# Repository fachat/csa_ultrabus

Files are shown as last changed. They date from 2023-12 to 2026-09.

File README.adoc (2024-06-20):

= csa_ultrabus
A backplane for CS/A, Apple II and RC2014 boards

Note: this can be used stand-alone, but is also a part of a larger set of repositories, with https://github.com/fachat/upet_family[upet_family] as the main repository.

The purpose of this backplane is to cross-enable the use of Apple II expansion cards and RC2014 boards 
on the CS/A65 bus http://www.6502.org/users/andre/csa/bus-1.1.html 

== General Discussion

The board combines three different types of busses:

CS/A65 bus:: 
	A 6502-based bus, with specific select lines and features.
	As, the main CPU uses an MMU, it has 20 address lines (A0-A19)
	to accomodate 1MByte of address space, and using the /MEMSEL
	line to select access to that space. Bank selection needs
	to be taken into account when accessing cards on the other 
	busses. A second select line /IOSEL selects a separate I/O space.
	It is 2k in size, but cards should preferrably be in the first
	256 byte.
	The rev 2 boards now have the long CS/A connectors, as well as 
	the short CS/A connectors. They are also specifically made to be
	used as extension bus to the [Ulti-PET](https://github.com/fachat/cbm_ultipet) machine.

Apple II::
	Apple II expansion slots are also 6502-based. The Apple II uses
	geographic addressing, i.e., each slot has a defined address 
	independent from which card is inserted. This means that address
	selection logic must be included on the board.

RC2014::
	This actually is a Z80-based bus, but boards exist that are
	actually built on 65xx/68xx-based chips - like the 6850-based
	serial interface card. The bus interface is severely different
	with /RD and /WR instead of R/-W and clock.
	Some boards even require timing on the select lines (only
	available on one RC2014 slot here)
	This has to be taken into account.

RC6502::
	This is a variation of the RC2014 bus. Unfortunately it is a 
	very raw mapping of the 6502 bus signals onto the bus.
	Therefore, it does not provide the ability to select specific
	memory areas. As it has 64k address space only, it is 
	only useful if an Apple II CPU is used, or the RC6502 is the
	CPU itself.

== Use Cases

=== CS/A main CPU using A2 and RC2014 boards

The CS/A main CPU uses a 6502, and has an MMU that extends the upper four
bits of the CPU address bus into eight bits, to create a physical 
address space of 1M, that can be selected on the bus.

As the typical system (e.g. PETCPU, or CPU+BIOS) fully occupies the
bank zero space (the lowest 64k on the bus address space),
the memory on the cards on the other busses have to be mapped into some other bank.
This can be done using jumpers.

For A2 boards, the I/O space is set to $02Cxxx, with the special geographic addressing taking place.
So, in the second 128 bytes all the I/O of the cards is located ($C08x-$C0Fx). These 128 byte can be
mapped into memory like in the Apple II, but also onto the /IOSEL space.

Memory access via the /MEMSEL line can be mapped to the /MREQ address space on the RC2014 line.
The /IOSEL line can be mapped to the /IOREQ address space on the RC2014
bus. 

=== CS/A UltraCPU using A2 and RC2014 boards

The UltraCPU works similar to the CS/A main CPU. Internally it uses all of bank zero.
It has one feature, however, that allows it to open up a window to the bus at either
$9xxx or $Cxxx. 

Therefore, the Apple II I/O window can be re-mapped to $009xxx or $00Cxxx on the CS/A bus.

=== Apple II DMA on a CS/A CPU/UltraCPU

Apple II cards can ask for a DMA slot, by pulling the /DMA line down. This separates the CS/A CPU
from the bus - i.e., puts the address, data, and control lines R/-W, /MEMSEL, /IOSEL, SYNC into high
impedance mode on the CPU board. The Apple II card then has to take over these lines.
As /MEMSEL does not exist on the A2 Bus, and the CS/A bus has four more address lines, these
lines are pulled low to auto-create an access to bank zero for any DMA triggered by an Apple II board.

This also enables the /MREQ address space on the RC2014 boards, so memory on these boards
can be used as well. Care has to be taken to not create bus conflicts by overlapping
address spaces.

It should be noted that any memory on a CPU board - UltraCPU specifically - cannot be 
addressed this way. Also, the CS/A PETCPU board lacks this feature. So, this is only
useful for a CPU+MMU+BIOS board system.

=== Apple II using CS/A and RC2014 boards

If there is a CPU board on the A2 bus that wants to take over the whole bus, no CPU board must be
plugged into the CS/A bus. Also, the /DMA feature must be jumpered permanently, to enable
addressing bank zero, and mapping the Apple II slot I/O onto $Cxxx.

This also enables the /MREQ address space on the RC2014 boards, so memory on these boards
can be used as well. Care has to be taken to not create bus conflicts by overlapping
address spaces.

To access CS/A I/O boards, the /IOSEL line needs to be jumpered to /SLOT2IO, so that it is mapped into 
the 256 byte of the Apple II slot 2 ROM space (the Ultrabus offers slots 3, 5, and 7)

To access RC2014 boards, the /IOREQ line must be jumperred to /SLOT6IO, mapping the 256 byte I/O space
into the 256 byte for Apple II slot 6 ROM.

=== RC6502 CPU using Apple II and CS/A boards

There is only one RC6502 slot available, by jumpering one of the RC2014 slots into an RC6502.
As the RC6502 is basically a 6502 bus, A16-A19 and /MEMSEL have to be jumpered to low similar
to the Apple CPU case. Also, the I/O slots are then available using the same mapping as
when the Apple II CPU is a bus master.

=== RC2014 CPU

Using an RC2014 CPU is NOT possible on this board.

== Build

To get the board built, KiCad schematics, gerber files, and a BOM with Mouser part numbers are provided in the repository.

== Revision History

- [R1.0A](https://github.com/fachat/csa_ultrabus/tree/r1.0a): the original Euro-PCB board. Built with Eagle

== Gallery

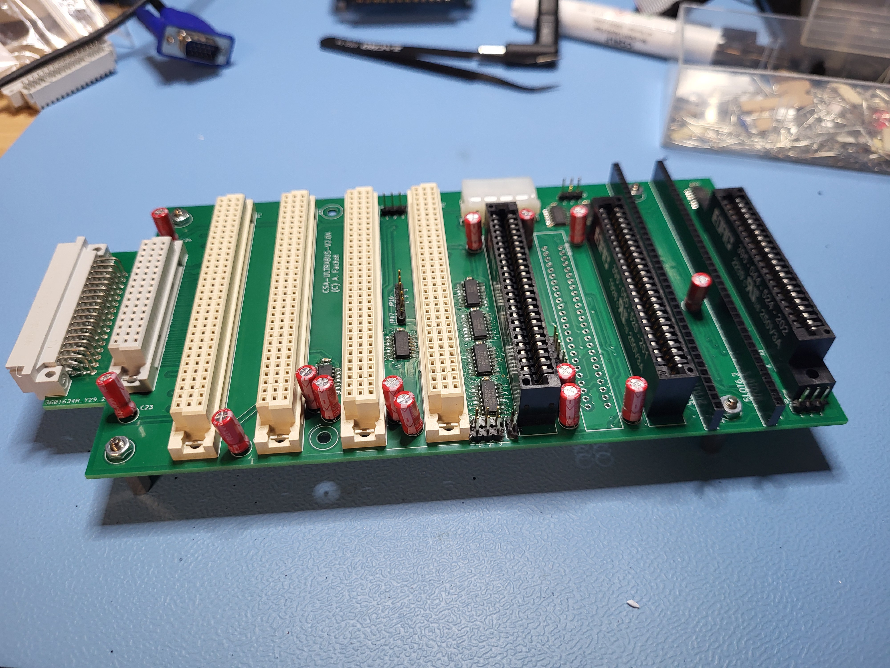
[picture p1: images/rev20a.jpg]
Revision 2.0A
 

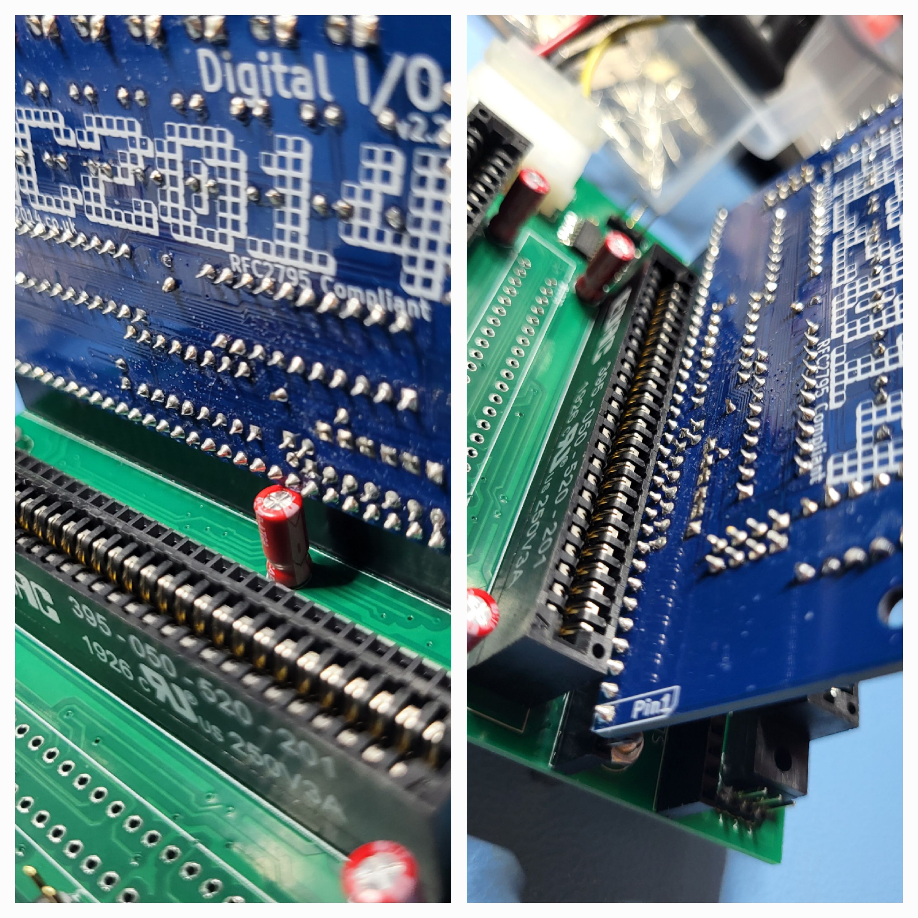
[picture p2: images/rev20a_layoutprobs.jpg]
Layout problems with revision 2.0A - fixed in 2.0B
 

=== Rev 1.0

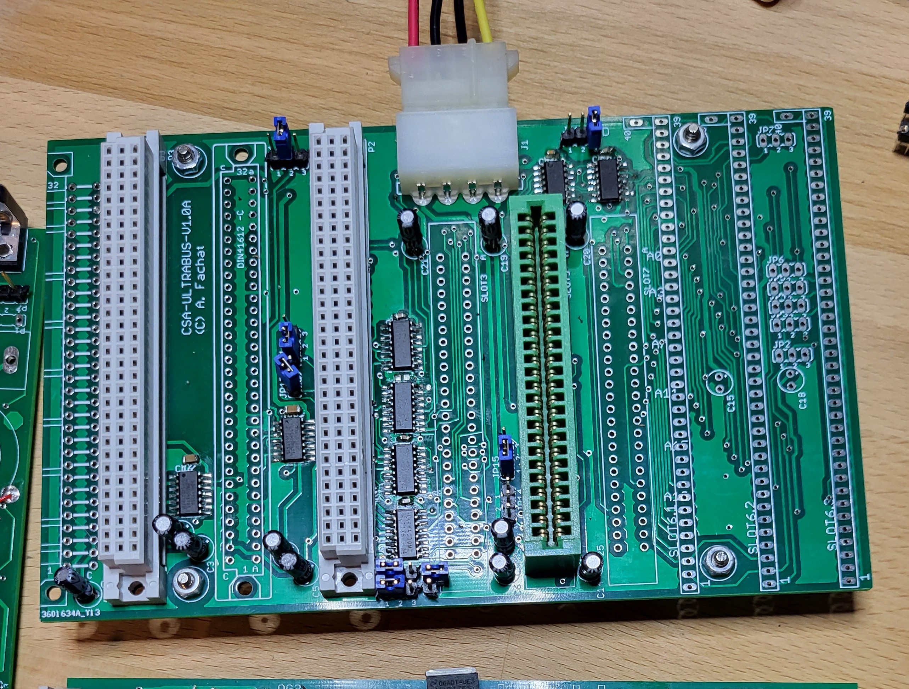
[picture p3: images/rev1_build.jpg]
Partially populated pcb during build
 

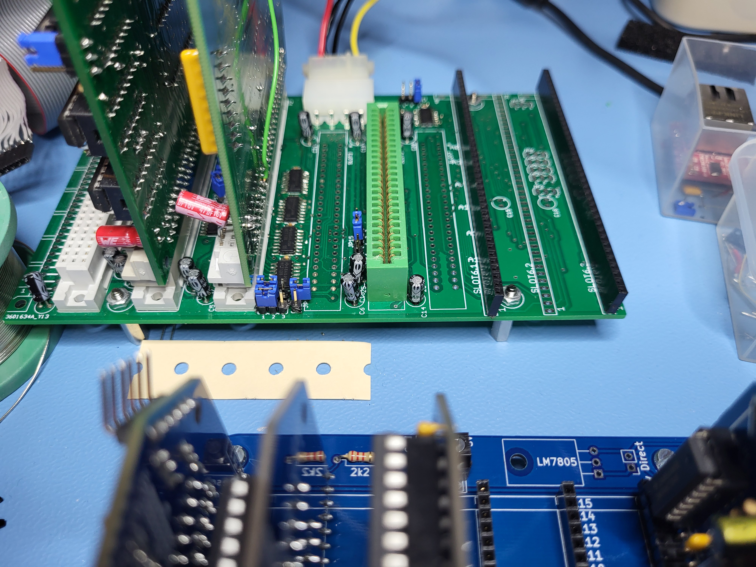
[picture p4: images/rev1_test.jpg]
PCB during test


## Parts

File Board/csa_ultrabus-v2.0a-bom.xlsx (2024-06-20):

Source: | /home/fachat/8bit/8bitgit/Eagle/work/CSA_ULTRABUS_V2.0A/csa_ultrabus_v2.kicad_sch
Date: | Fri Feb 16 13:55:04 2024
Tool: | Eeschema 7.0.10
Generator: | /app/share/kicad/plugins/bom_csv_grouped_by_value_with_fp.py
Component Count: | 62
Ref | Qnty | orig | Value | Cmp name | Footprint | Description | Vendor | DNP | Alt
C1, C3, C4, C5, C6, C13, C14, C15, C17, C18, C19, C20, C21, C23, C24 | 15 |  | 47u | CPOL-EUE2.5-5 | csa_ultrabus_v2:E2,5-5 | POLARIZED CAPACITOR, European symbol | 710-860010372004 | 860010372004
C2, C7, C8, C9, C10, C11, C12, C16, C22 | 9 |  | 100n | C-EUC0603 | csa_ultrabus_v2:C0603 | CAPACITOR, European symbol | 710-885012206020 | 885012206020
IC1 | 1 |  | 7404D | 7404D | csa_ultrabus_v2:SO14 |  | 771-74HCT04D-Q100118 | 74HCT04D-Q100,118
IC2, IC3, IC4, IC5, IC9 | 5 |  | 74138D | 74138D | csa_ultrabus_v2:SO16 |  | 595-SN74HCT138DR | SN74HCT138DR | 771-74HCT138D-T
IC6 | 1 |  | 7400D | 7400D | csa_ultrabus_v2:SO14 |  | 771-74HCT00D-Q100118 | 74HCT00D-Q100,118
IC7, IC8 | 2 |  | 74125D | 74125D | csa_ultrabus_v2:SO14 |  | 771-74HCT125D-Q100J | 74HCT125D-Q100J
J1 | 1 |  | FLOP-4W827001 | FLOP-4W827001 | csa_ultrabus_v2:827001 | MATE N-LOCK Floppy / HDD conector | 571-6417371 | 641737-1 | https://www.reichelt.de/stromversorgungsstecker-f-5-1-4-zoll-print-gew--psw-5-p14915.html?trstct=pol_3&nbc=1
JP1, JP2, JP9, JP10, JP11, JP14, JP15, JP16 |  | 8 | JP2E | JP2E | csa_ultrabus_v2:JP2
JP8, JP17 |  | 2 | JP1E | JP1E | csa_ultrabus_v2:JP1
 | 1 |  |  |  |  | pin strip straight 20 pin | 649-1012937892001BLF | 10129378-920001BLF
P1, P2, P3, P4 | 4 |  | CSABUSSOCK180 | CSABUSSOCK180 | csa_ultrabus_v2:CSABUSSOCK180 |  | 649-8609464814T5F1LF | 86094648114T55F1LF
SLOT3, SLOT5, SLOT7 | 3 |  | A2SLOT | A2SLOT | csa_ultrabus_v2:FE100-25 |  | 587-395-050 | 395-050-520-202 | 587-395-050-520-201 | 395-050-520-201
SLOT6.1, SLOT6.2 | 2 |  | RC2014/6502 | RC2014/6502 | csa_ultrabus_v2:SIL40 |  | 200-SSW14006TS | SSW-140-06-T-S | 872-920-0215-01 | 920-0215-01
U$1 | 1 |  | CSASHORTBUSFS | CSASHORTBUSFS | csa_ultrabus_v2:FABC48S2 |  | 649-93488314H55V1LF | 86093488314H55V1LF
U$2 | 1 |  | CSASHORTBUSMA | CSASHORTBUSMA | csa_ultrabus_v2:MABC48B2 |  | 649-8693487313765ELF | 86093487313765ELF
X1 | 1 |  | PORT_EXPANSION_64_CONN | PORT_EXPANSION_64_CONN | csa_ultrabus_v2:FE100-22-2 |  | 587-395-044 | 395-044-520-202

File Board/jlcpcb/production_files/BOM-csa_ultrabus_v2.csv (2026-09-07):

Comment | Designator | Footprint | LCSC | Quantity
0 | R25,R26,R27,R28 | R_0603_1608Metric_Pad0.98x0.95mm_HandSolder | C21189 | 4
0.01uF low ESR | C41 | C_0603_1608Metric_Pad1.08x0.95mm_HandSolder | C57112 | 1
1.1k | R10 | R_0603_1608Metric_Pad0.98x0.95mm_HandSolder | C22764 | 1
100k | R8 | R_0603_1608Metric_Pad0.98x0.95mm_HandSolder | C25803 | 1
100n | C25,C31,C32,C37,C40,C43,C46 | C_0603_1608Metric_Pad1.08x0.95mm_HandSolder | C14663 | 7
10k | R1,R14,R18,R22,R30,R36,R39,R41,R43,R9 | R_0603_1608Metric_Pad0.98x0.95mm_HandSolder | C25804 | 10
10u | C27,C28,C29,C35,C36,C38 | C_1206_3216Metric_Pad1.33x1.80mm_HandSolder | C33546014 | 6
15uH | L2 | L_APV_APH0630 | C5189959 | 1
1N4148 | D11,D12 | D_SOD-323_HandSoldering | C2128 | 2
1k, >=0.3W | R29 | R_0603_1608Metric_Pad0.98x0.95mm_HandSolder | C5886053 | 1
1u | C26 | C_1206_3216Metric_Pad1.33x1.80mm_HandSolder | C1848 | 1
2.2k | R37,R42 | R_0603_1608Metric_Pad0.98x0.95mm_HandSolder | C4190 | 2
220u | C42 | CP_Elec_10x10 | C125977 | 1
22u | C30,C33,C34,C39,C45,C47 | C_1206_3216Metric_Pad1.33x1.80mm_HandSolder | C12891 | 6
2k2 | R13,R33,R34,R45,R46,R47,R48,R6 | R_0603_1608Metric_Pad0.98x0.95mm_HandSolder | C4190 | 8
36k | R11,R35 | R_0603_1608Metric_Pad0.98x0.95mm_HandSolder | C23147 | 2
3k3 | R4 | R_0603_1608Metric_Pad0.98x0.95mm_HandSolder | C22978 | 1
4.7uH | L1 | L_APV_ANR4030 | C57269 | 1
420 | R12,R5 | R_0603_1608Metric_Pad0.98x0.95mm_HandSolder | C23057 | 2
47k | R17 | R_0603_1608Metric_Pad0.98x0.95mm_HandSolder | C25819 | 1
47u | C1,C13,C14,C15,C17,C18,C19,C20,C21,C23,C24,C3,C4,C5,C6 | E2,5-5 | C713185 | 15
5.1k | R7 | R_0603_1608Metric_Pad0.98x0.95mm_HandSolder | C23186 | 1
560 | R38,R44 | R_0603_1608Metric_Pad0.98x0.95mm_HandSolder | C23204 | 2
680 | R16,R20,R24 | R_0603_1608Metric_Pad0.98x0.95mm_HandSolder | C23228 | 3
7400D | IC6 | SO14 | C282337 | 1
7404D | IC1 | SO14 | C6766 | 1
74125D | IC7,IC8 | SO14 | C5962 | 2
74138D | IC2,IC3,IC4,IC5,IC9 | SO16 | C352958 | 5
8.2k | R21 | R_0603_1608Metric_Pad0.98x0.95mm_HandSolder | C25981 | 1
8.6k | R40 | R_0603_1608Metric_Pad0.98x0.95mm_HandSolder | C2924154 | 1
A2SLOT | SLOT3,SLOT5,SLOT7 | FE100-25 | C5173308 | 3
AP63205WU | U1 | TSOT-23-6 | C2071056 | 1
B340A | D4 | D_SMA_Handsoldering | C3018525 | 1
BC847 | Q7,Q8 | SOT-23 | C7420337 | 2
BC857 | Q1,Q2,Q3 | SOT-23 | C20069137 | 3
C-EUC0603 | C10,C11,C12,C16,C2,C22,C7,C8,C9 | C0603 | C14663 | 9
CH224K | U9 | SSOP-10-1EP_3.9x4.9mm_P1mm_EP2.1x3.3mm | C970725 | 1
CSABUSSOCK180 | P1,P2,P3,P4 | CSABUSSOCK180 | C53202145 | 4
CSASHORTBUSFS | U$1 | FABC48S2 | C5377847 | 1
CSASHORTBUSMA | U$2 | MABC48B2 | C5173369 | 1
JP1E | JP17,JP18,JP19,JP8 | JP1 | C7494857 | 4
JP2E | JP1,JP10,JP11,JP14,JP15,JP16,JP2,JP9 | JP2 | C6332196 | 8
L7812 | U2 | TO-252-2 | C26184 | 1
L7905 | U5 | TO-252-3_TabPin2 | C962758 | 1
LDI1117 | UX3 | SOT-223 | C6186 | 1
LED | D1,D2,D3,D6,D7 | D_0603_1608Metric_Pad1.05x0.95mm_HandSolder | C12065 | 5
LED | D10,D13,D14,D8,D9 | D_0603_1608Metric_Pad1.05x0.95mm_HandSolder | C7496820 | 5
PORT_EXPANSION_64_CONN | X1 | FE100-22-2 | C21261712 | 1
RC2014/6502 | SLOT6.1,SLOT6.2 | SIL40 | C18078141 | 2
TL431 | U11,U12 | SOT-23 | C181103 | 2
TL431DBZ | U6,U7,U8 | SOT-23 | C181103 | 3
TPS5430DDA | U4 | TI_SO-PowerPAD-8_ThermalVias | C9864 | 1
USB_C_Receptacle_USB2.0_16P | J3 | USB_C_Receptacle_GCT_USB4105-xx-A_16P_TopMnt_Horizontal | C2765186 | 1

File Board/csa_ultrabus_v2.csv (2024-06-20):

Id | Designator | Footprint | Quantity | Designation | Supplier and ref
1 | IC5,IC9,IC3,IC4,IC2 | SO16 | 5 | 74138D
2 | C4,C14,C23,C18,C17,C24,C5,C15,C13,C21,C3,C6,C1,C20,C19 | E2,5-5 | 15 | 47u
3 | JP8,JP17 | JP1 | 2 | JP1E
4 | P2,P4,P3,P1 | CSABUSSOCK180 | 4 | CSABUSSOCK180
5 | C11,C8,C9,C16,C12,C2,C10,C22,C7 | C0603 | 9 | C-EUC0603
6 | JP11,JP15,JP16,JP1,JP14,JP9,JP2,JP10 | JP2 | 8 | JP2E
7 | H2,H5,H6,H1,H4,H3 | 3,2 | 6 | MOUNT-HOLE3.2
8 | SLOT5,SLOT3,SLOT7 | FE100-25 | 3 | A2SLOT
9 | SLOT6.1,SLOT6.2 | SIL40 | 2 | RC2014/6502
10 | U$1 | FABC48S2 | 1 | CSASHORTBUSFS
11 | IC8,IC7 | SO14 | 2 | 74125D
12 | U$2 | MABC48B2 | 1 | CSASHORTBUSMA
13 | IC6 | SO14 | 1 | 7400D
14 | IC1 | SO14 | 1 | 7404D
15 | X1 | FE100-22-2 | 1 | PORT_EXPANSION_64_CONN
16 | R1 | R_Axial_DIN0204_L3.6mm_D1.6mm_P2.54mm_Vertical | 1 | 10k
17 | J1 | 827001 | 1 | FLOP-4W827001

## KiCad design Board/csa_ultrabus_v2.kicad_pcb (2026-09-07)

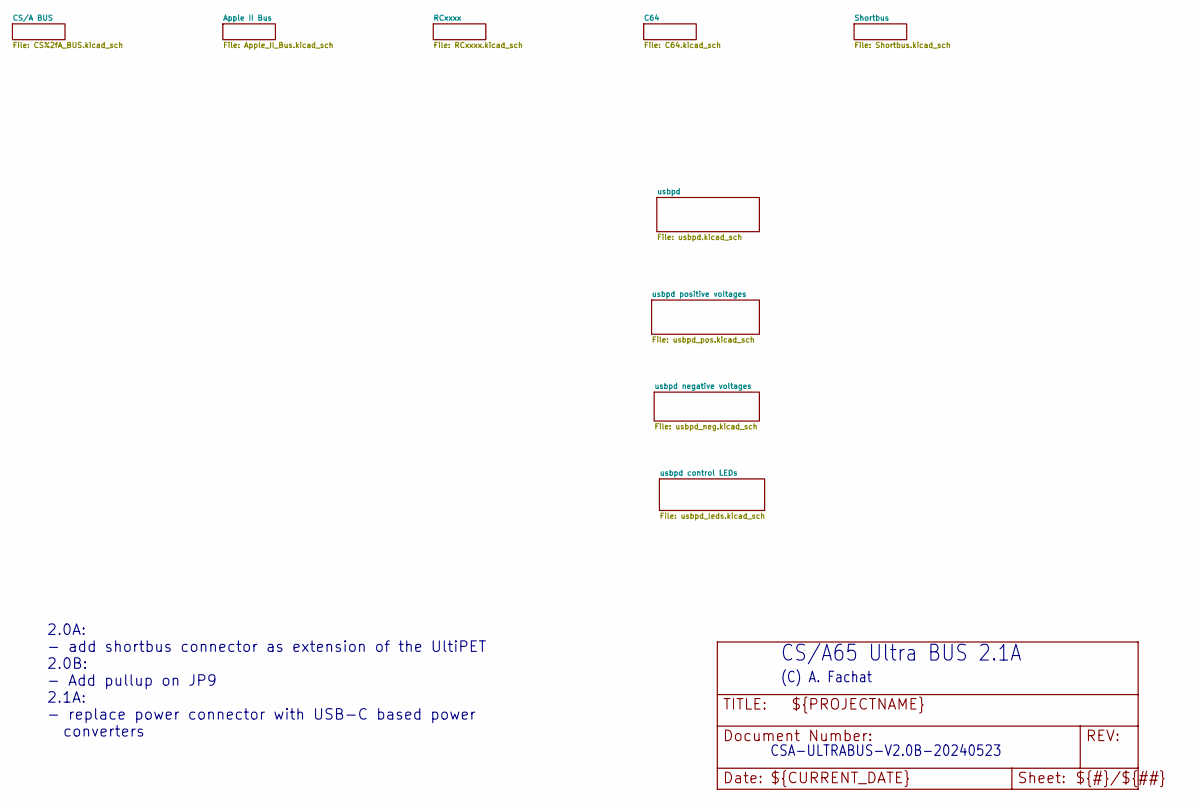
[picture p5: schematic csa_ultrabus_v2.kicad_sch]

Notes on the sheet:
2.0A: - add shortbus connector as extension of the UltiPET 2.0B: - Add pullup on JP9 2.1A: - replace power connector with USB-C based power converters
(C) A. Fachat
CS/A65 Ultra BUS 2.1A
CSA-ULTRABUS-V2.0B-20240523

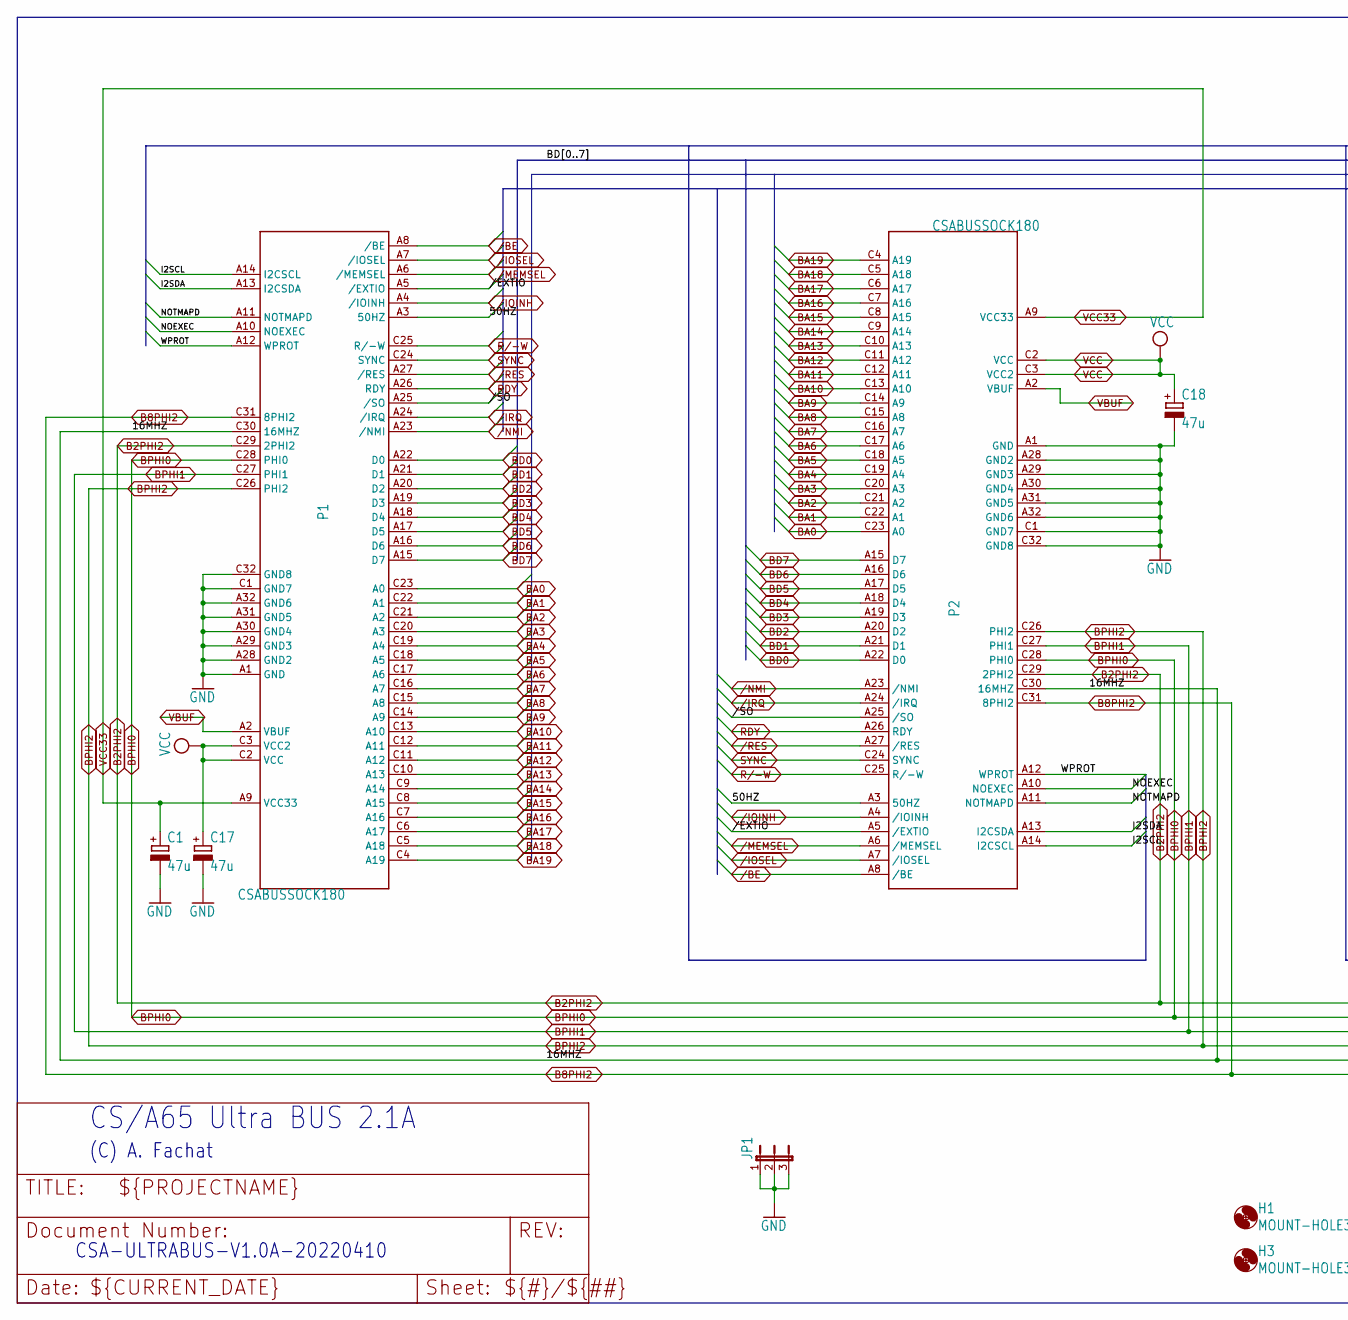
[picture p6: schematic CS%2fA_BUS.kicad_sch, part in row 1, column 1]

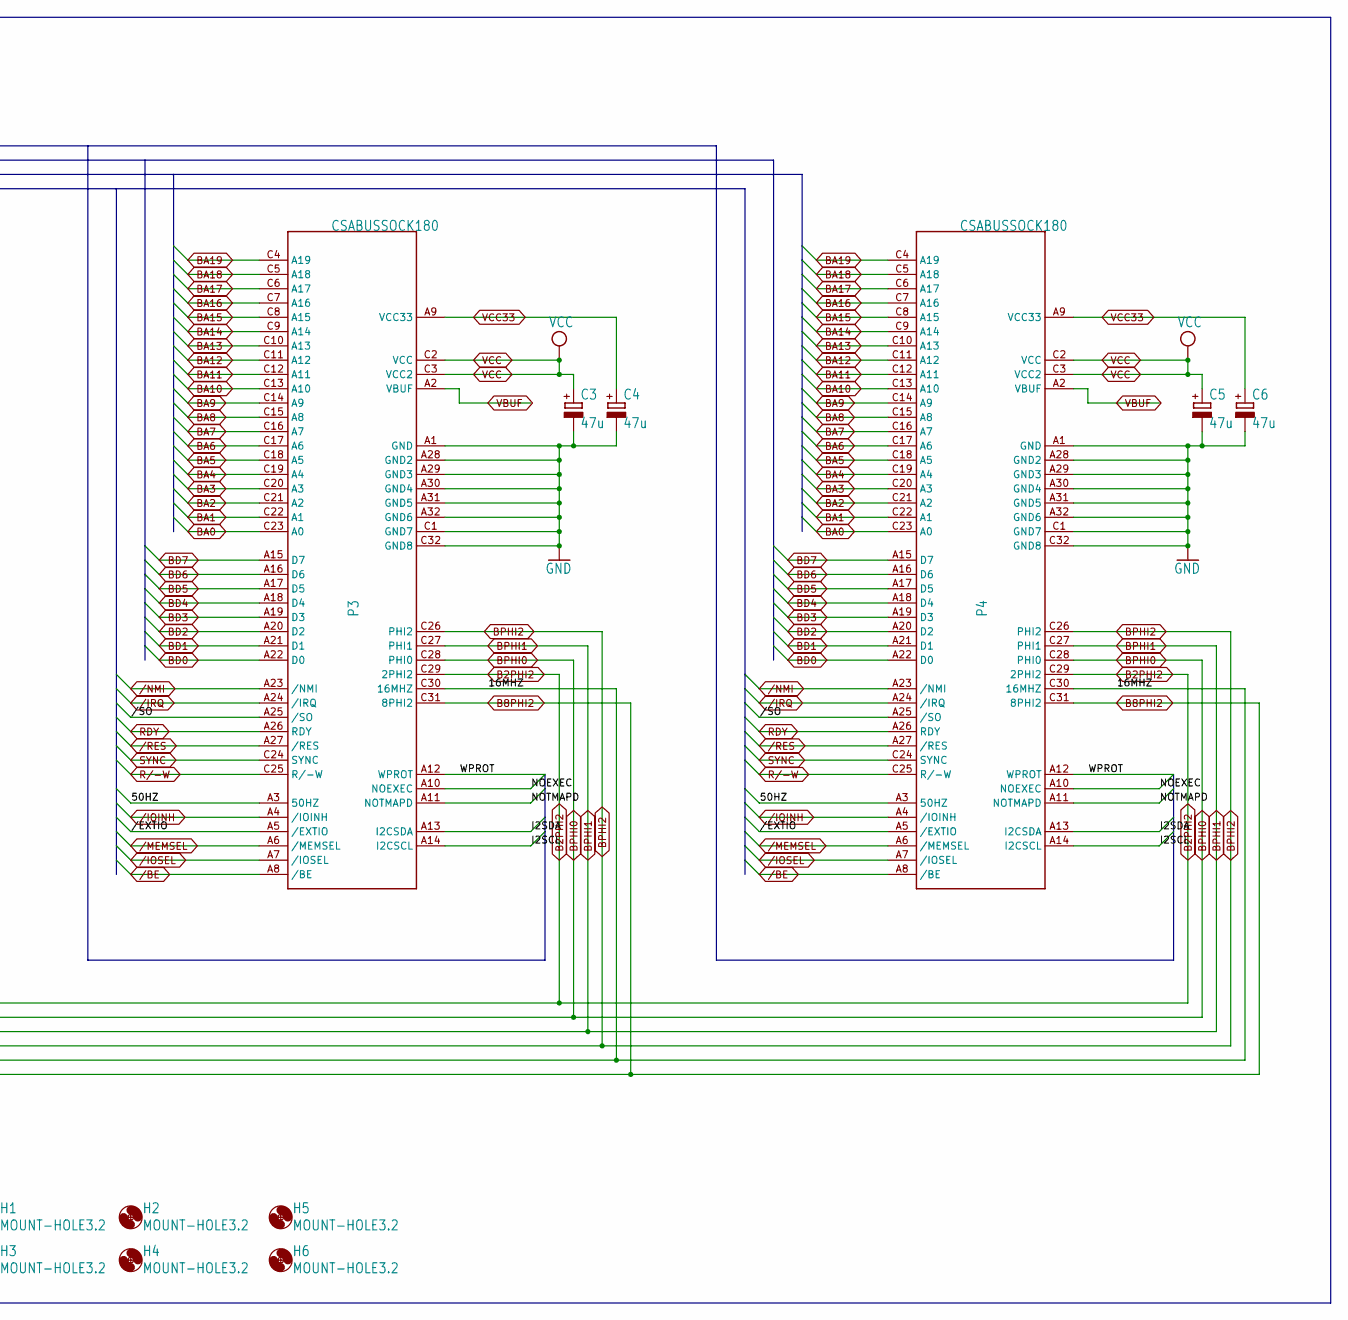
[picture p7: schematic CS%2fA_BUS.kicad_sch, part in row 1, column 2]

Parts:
C1, C3, C4, C5, C6, C17, C18: 47u; E2,5-5; LCSC C713185
H1, H2, H3, H4, H5, H6: MOUNT-HOLE3.2; 3,2
JP1: JP2E; JP2; LCSC C6332196
P1, P2, P3, P4: CSABUSSOCK180; LCSC C53202145

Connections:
5V: C3.+, C5.+, C17.+, C18.+, P1.C2 (VCC), P1.C3 (VCC2), P2.C2 (VCC), P2.C3 (VCC2), P3.C2 (VCC), P3.C3 (VCC2), P4.C2 (VCC), P4.C3 (VCC2); also elsewhere on the board
/CS/A BUS/16MHZ: P1.C30 (16MHZ), P2.C30 (16MHZ), P3.C30 (16MHZ), P4.C30 (16MHZ)
/CS/A BUS/50HZ: P1.A3 (50HZ), P2.A3 (50HZ), P3.A3 (50HZ), P4.A3 (50HZ)
/CS/A BUS/I2SCL: P1.A14 (I2CSCL), P2.A14 (I2CSCL), P3.A14 (I2CSCL), P4.A14 (I2CSCL)
/CS/A BUS/I2SDA: P1.A13 (I2CSDA), P2.A13 (I2CSDA), P3.A13 (I2CSDA), P4.A13 (I2CSDA)
/CS/A BUS/NOEXEC: P1.A10 (NOEXEC), P2.A10 (NOEXEC), P3.A10 (NOEXEC), P4.A10 (NOEXEC)
/CS/A BUS/NOTMAPD: P1.A11 (NOTMAPD), P2.A11 (NOTMAPD), P3.A11 (NOTMAPD), P4.A11 (NOTMAPD)
/CS/A BUS/WPROT: P1.A12 (WPROT), P2.A12 (WPROT), P3.A12 (WPROT), P4.A12 (WPROT)
/CS/A BUS//EXTIO: P1.A5 (/EXTIO), P2.A5 (/EXTIO), P3.A5 (/EXTIO), P4.A5 (/EXTIO)
/CS/A BUS//SO: P1.A25 (/SO), P2.A25 (/SO), P3.A25 (/SO), P4.A25 (/SO)
B2PHI2: P1.C29 (2PHI2), P2.C29 (2PHI2), P3.C29 (2PHI2), P4.C29 (2PHI2); also elsewhere on the board
B8PHI2: P1.C31 (8PHI2), P2.C31 (8PHI2), P3.C31 (8PHI2), P4.C31 (8PHI2); also elsewhere on the board
BA0: P1.C23 (A0), P2.C23 (A0), P3.C23 (A0), P4.C23 (A0); also elsewhere on the board
BA1: P1.C22 (A1), P2.C22 (A1), P3.C22 (A1), P4.C22 (A1); also elsewhere on the board
BA2: P1.C21 (A2), P2.C21 (A2), P3.C21 (A2), P4.C21 (A2); also elsewhere on the board
BA3: P1.C20 (A3), P2.C20 (A3), P3.C20 (A3), P4.C20 (A3); also elsewhere on the board
BA4: P1.C19 (A4), P2.C19 (A4), P3.C19 (A4), P4.C19 (A4); also elsewhere on the board
BA5: P1.C18 (A5), P2.C18 (A5), P3.C18 (A5), P4.C18 (A5); also elsewhere on the board
BA6: P1.C17 (A6), P2.C17 (A6), P3.C17 (A6), P4.C17 (A6); also elsewhere on the board
BA7: P1.C16 (A7), P2.C16 (A7), P3.C16 (A7), P4.C16 (A7); also elsewhere on the board
BA8: P1.C15 (A8), P2.C15 (A8), P3.C15 (A8), P4.C15 (A8); also elsewhere on the board
BA9: P1.C14 (A9), P2.C14 (A9), P3.C14 (A9), P4.C14 (A9); also elsewhere on the board
BA10: P1.C13 (A10), P2.C13 (A10), P3.C13 (A10), P4.C13 (A10); also elsewhere on the board
BA11: P1.C12 (A11), P2.C12 (A11), P3.C12 (A11), P4.C12 (A11); also elsewhere on the board
BA12: P1.C11 (A12), P2.C11 (A12), P3.C11 (A12), P4.C11 (A12); also elsewhere on the board
BA13: P1.C10 (A13), P2.C10 (A13), P3.C10 (A13), P4.C10 (A13); also elsewhere on the board
BA14: P1.C9 (A14), P2.C9 (A14), P3.C9 (A14), P4.C9 (A14); also elsewhere on the board
BA15: P1.C8 (A15), P2.C8 (A15), P3.C8 (A15), P4.C8 (A15); also elsewhere on the board
BA16: P1.C7 (A16), P2.C7 (A16), P3.C7 (A16), P4.C7 (A16); also elsewhere on the board
BA17: P1.C6 (A17), P2.C6 (A17), P3.C6 (A17), P4.C6 (A17); also elsewhere on the board
BA18: P1.C5 (A18), P2.C5 (A18), P3.C5 (A18), P4.C5 (A18); also elsewhere on the board
BA19: P1.C4 (A19), P2.C4 (A19), P3.C4 (A19), P4.C4 (A19); also elsewhere on the board
BD0: P1.A22 (D0), P2.A22 (D0), P3.A22 (D0), P4.A22 (D0); also elsewhere on the board
BD1: P1.A21 (D1), P2.A21 (D1), P3.A21 (D1), P4.A21 (D1); also elsewhere on the board
BD2: P1.A20 (D2), P2.A20 (D2), P3.A20 (D2), P4.A20 (D2); also elsewhere on the board
BD3: P1.A19 (D3), P2.A19 (D3), P3.A19 (D3), P4.A19 (D3); also elsewhere on the board
BD4: P1.A18 (D4), P2.A18 (D4), P3.A18 (D4), P4.A18 (D4); also elsewhere on the board
BD5: P1.A17 (D5), P2.A17 (D5), P3.A17 (D5), P4.A17 (D5); also elsewhere on the board
BD6: P1.A16 (D6), P2.A16 (D6), P3.A16 (D6), P4.A16 (D6); also elsewhere on the board
BD7: P1.A15 (D7), P2.A15 (D7), P3.A15 (D7), P4.A15 (D7); also elsewhere on the board
BPHI0: P1.C28 (PHI0), P2.C28 (PHI0), P3.C28 (PHI0), P4.C28 (PHI0); also elsewhere on the board
BPHI1: P1.C27 (PHI1), P2.C27 (PHI1), P3.C27 (PHI1), P4.C27 (PHI1); also elsewhere on the board
BPHI2: P1.C26 (PHI2), P2.C26 (PHI2), P3.C26 (PHI2), P4.C26 (PHI2); also elsewhere on the board
GND: C1.-, C3.-, C4.-, C5.-, C6.-, C17.-, C18.-, JP1.1, JP1.2, JP1.3, P1.A1 (GND), P1.A28 (GND2), P1.A29 (GND3), P1.A30 (GND4), P1.A31 (GND5), P1.A32 (GND6), P1.C1 (GND7), P1.C32 (GND8), P2.A1 (GND), P2.A28 (GND2), P2.A29 (GND3), P2.A30 (GND4), P2.A31 (GND5), P2.A32 (GND6), P2.C1 (GND7), P2.C32 (GND8), P3.A1 (GND), P3.A28 (GND2), P3.A29 (GND3), P3.A30 (GND4), P3.A31 (GND5), P3.A32 (GND6), P3.C1 (GND7), P3.C32 (GND8), P4.A1 (GND), P4.A28 (GND2), P4.A29 (GND3), P4.A30 (GND4), P4.A31 (GND5), P4.A32 (GND6), P4.C1 (GND7), P4.C32 (GND8); also elsewhere on the board
RDY: P1.A26 (RDY), P2.A26 (RDY), P3.A26 (RDY), P4.A26 (RDY); also elsewhere on the board
R/-W: P1.C25 (R/-W), P2.C25 (R/-W), P3.C25 (R/-W), P4.C25 (R/-W); also elsewhere on the board
SYNC: P1.C24 (SYNC), P2.C24 (SYNC), P3.C24 (SYNC), P4.C24 (SYNC); also elsewhere on the board
V33: C1.+, C4.+, C6.+, P1.A9 (VCC33), P2.A9 (VCC33), P3.A9 (VCC33), P4.A9 (VCC33); also elsewhere on the board
VBUF: P1.A2 (VBUF), P2.A2 (VBUF), P3.A2 (VBUF), P4.A2 (VBUF); also elsewhere on the board
/BE: P1.A8 (/BE), P2.A8 (/BE), P3.A8 (/BE), P4.A8 (/BE); also elsewhere on the board
/IOINH: P1.A4 (/IOINH), P2.A4 (/IOINH), P3.A4 (/IOINH), P4.A4 (/IOINH); also elsewhere on the board
/IOSEL: P1.A7 (/IOSEL), P2.A7 (/IOSEL), P3.A7 (/IOSEL), P4.A7 (/IOSEL); also elsewhere on the board
/IRQ: P1.A24 (/IRQ), P2.A24 (/IRQ), P3.A24 (/IRQ), P4.A24 (/IRQ); also elsewhere on the board
/MEMSEL: P1.A6 (/MEMSEL), P2.A6 (/MEMSEL), P3.A6 (/MEMSEL), P4.A6 (/MEMSEL); also elsewhere on the board
/NMI: P1.A23 (/NMI), P2.A23 (/NMI), P3.A23 (/NMI), P4.A23 (/NMI); also elsewhere on the board
/RES: P1.A27 (/RES), P2.A27 (/RES), P3.A27 (/RES), P4.A27 (/RES); also elsewhere on the board

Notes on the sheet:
CSA-ULTRABUS-V1.0A-20220410
CS/A65 Ultra BUS 2.1A
(C) A. Fachat

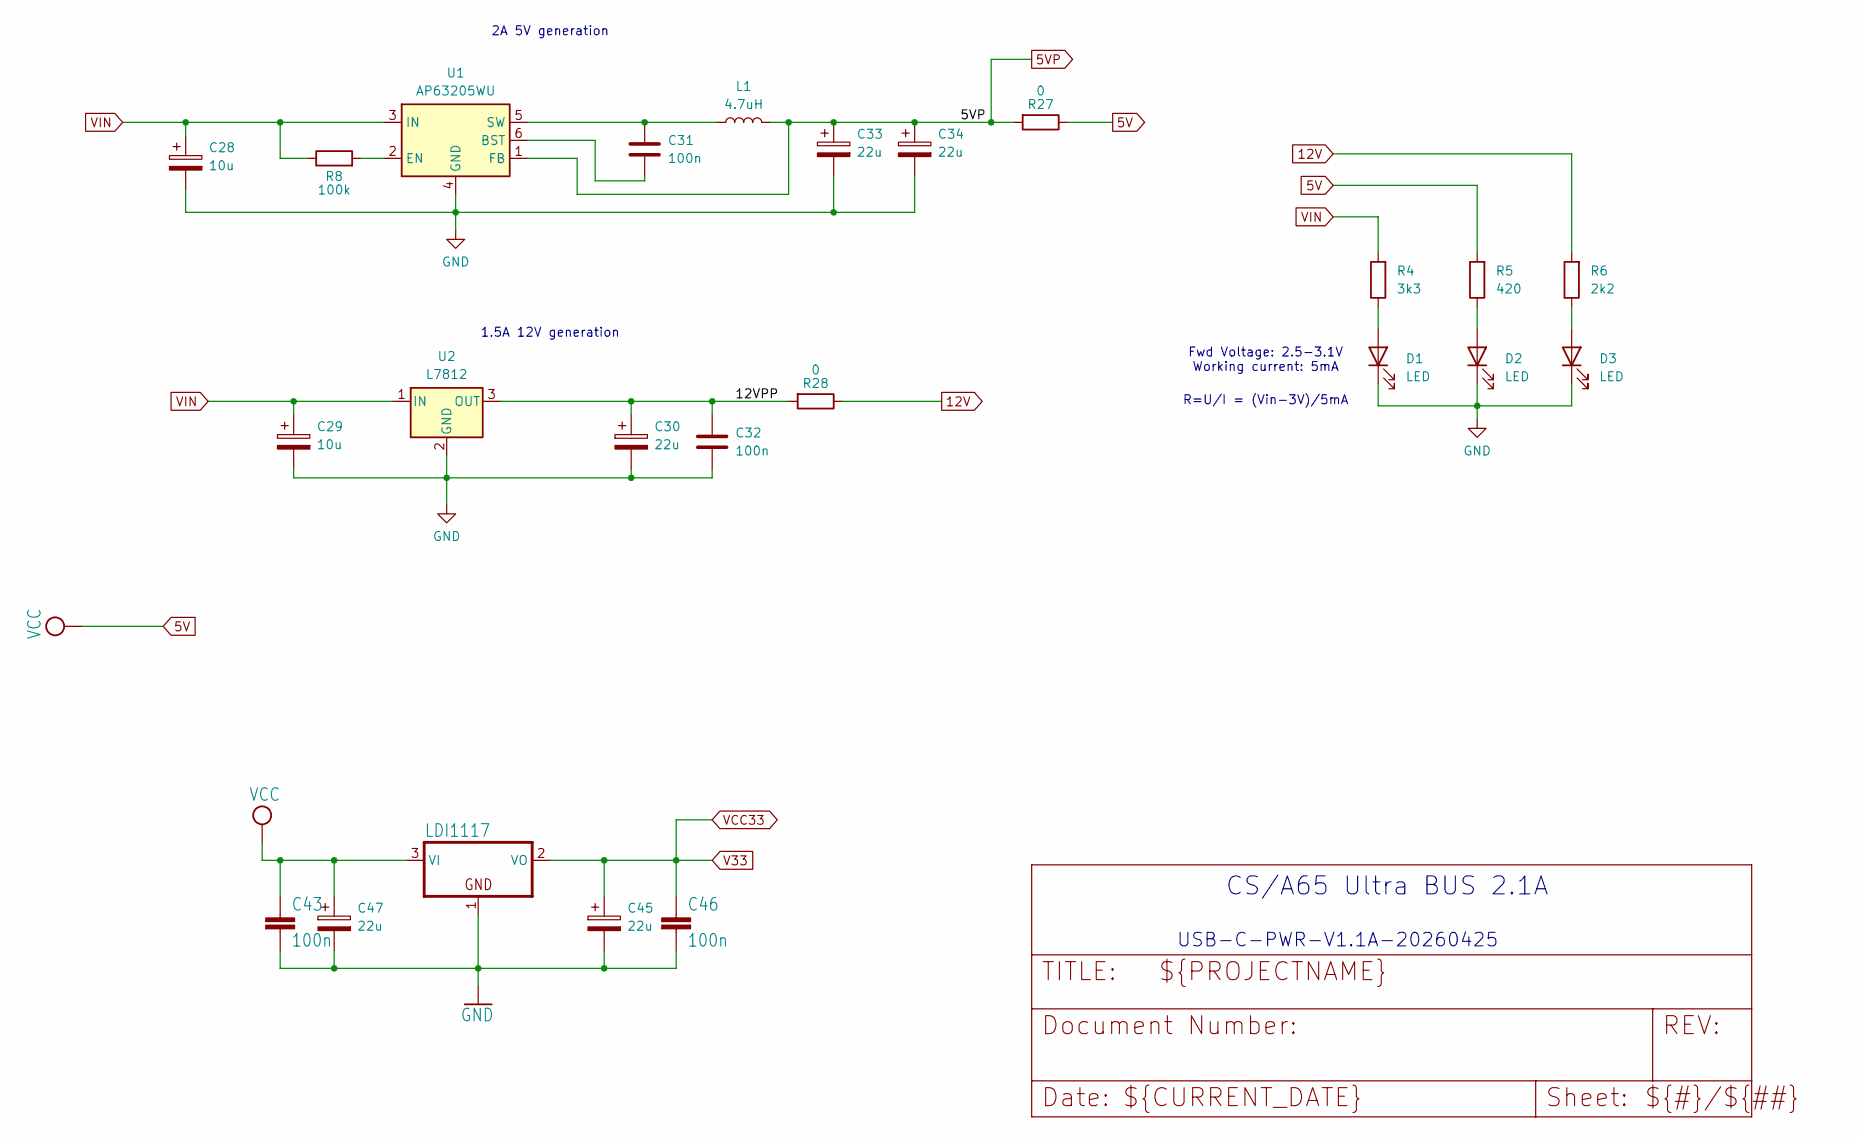
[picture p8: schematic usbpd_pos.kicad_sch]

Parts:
C28, C29: 10u; C_1206_3216Metric_Pad1.33x1.80mm_HandSolder; LCSC C33546014
C30, C33, C34, C45, C47: 22u; C_1206_3216Metric_Pad1.33x1.80mm_HandSolder; LCSC C12891
C31, C32, C43, C46: 100n; C_0603_1608Metric_Pad1.08x0.95mm_HandSolder; LCSC C14663
D1, D2, D3: LED; D_0603_1608Metric_Pad1.05x0.95mm_HandSolder; LCSC C12065
L1: 4.7uH; L_APV_ANR4030; LCSC C57269
R4: 3k3; R_0603_1608Metric_Pad0.98x0.95mm_HandSolder; LCSC C22978
R5: 420; R_0603_1608Metric_Pad0.98x0.95mm_HandSolder; LCSC C23057
R6: 2k2; R_0603_1608Metric_Pad0.98x0.95mm_HandSolder; LCSC C4190
R8: 100k; R_0603_1608Metric_Pad0.98x0.95mm_HandSolder; LCSC C25803
R27, R28: 0; R_0603_1608Metric_Pad0.98x0.95mm_HandSolder; LCSC C21189
U1: AP63205WU; TSOT-23-6; LCSC C2071056
U2: L7812; TO-252-2; LCSC C26184
UX3: LDI1117; SOT-223; LCSC C6186

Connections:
5V: C43.1, C47.1, R5.2, R27.1, UX3.3 (VI); also elsewhere on the board
5VP: C33.1, C34.1, L1.2, R27.2, U1.1 (FB); also elsewhere on the board
12V: R6.2, R28.1; also elsewhere on the board
/usbpd positive voltages/12VPP: C30.1, C32.2, R28.2, U2.3 (OUT)
GND: C28.2, C29.2, C30.2, C32.1, C33.2, C34.2, C43.2, C45.2, C46.2, C47.2, D1.1 (K), D2.1 (K), D3.1 (K), U1.4 (GND), U2.2 (GND), UX3.1 (GND); also elsewhere on the board
unnamed: D1.2 (A), R4.1
unnamed: D2.2 (A), R5.1
unnamed: D3.2 (A), R6.1
unnamed: C31.1, U1.6 (BST)
unnamed: R8.2, U1.2 (EN)
unnamed: C31.2, L1.1, U1.5 (SW)
V33: C45.1, C46.1, UX3.2 (VO); also elsewhere on the board
VBUS: C28.1, C29.1, R4.2, R8.1, U1.3 (IN), U2.1 (IN); also elsewhere on the board

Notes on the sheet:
R=U/I = (Vin-3V)/5mA
1.5A 12V generation
2A 5V generation
CS/A65 Ultra BUS 2.1A
Fwd Voltage: 2.5-3.1V Working current: 5mA
USB-C-PWR-V1.1A-20260425

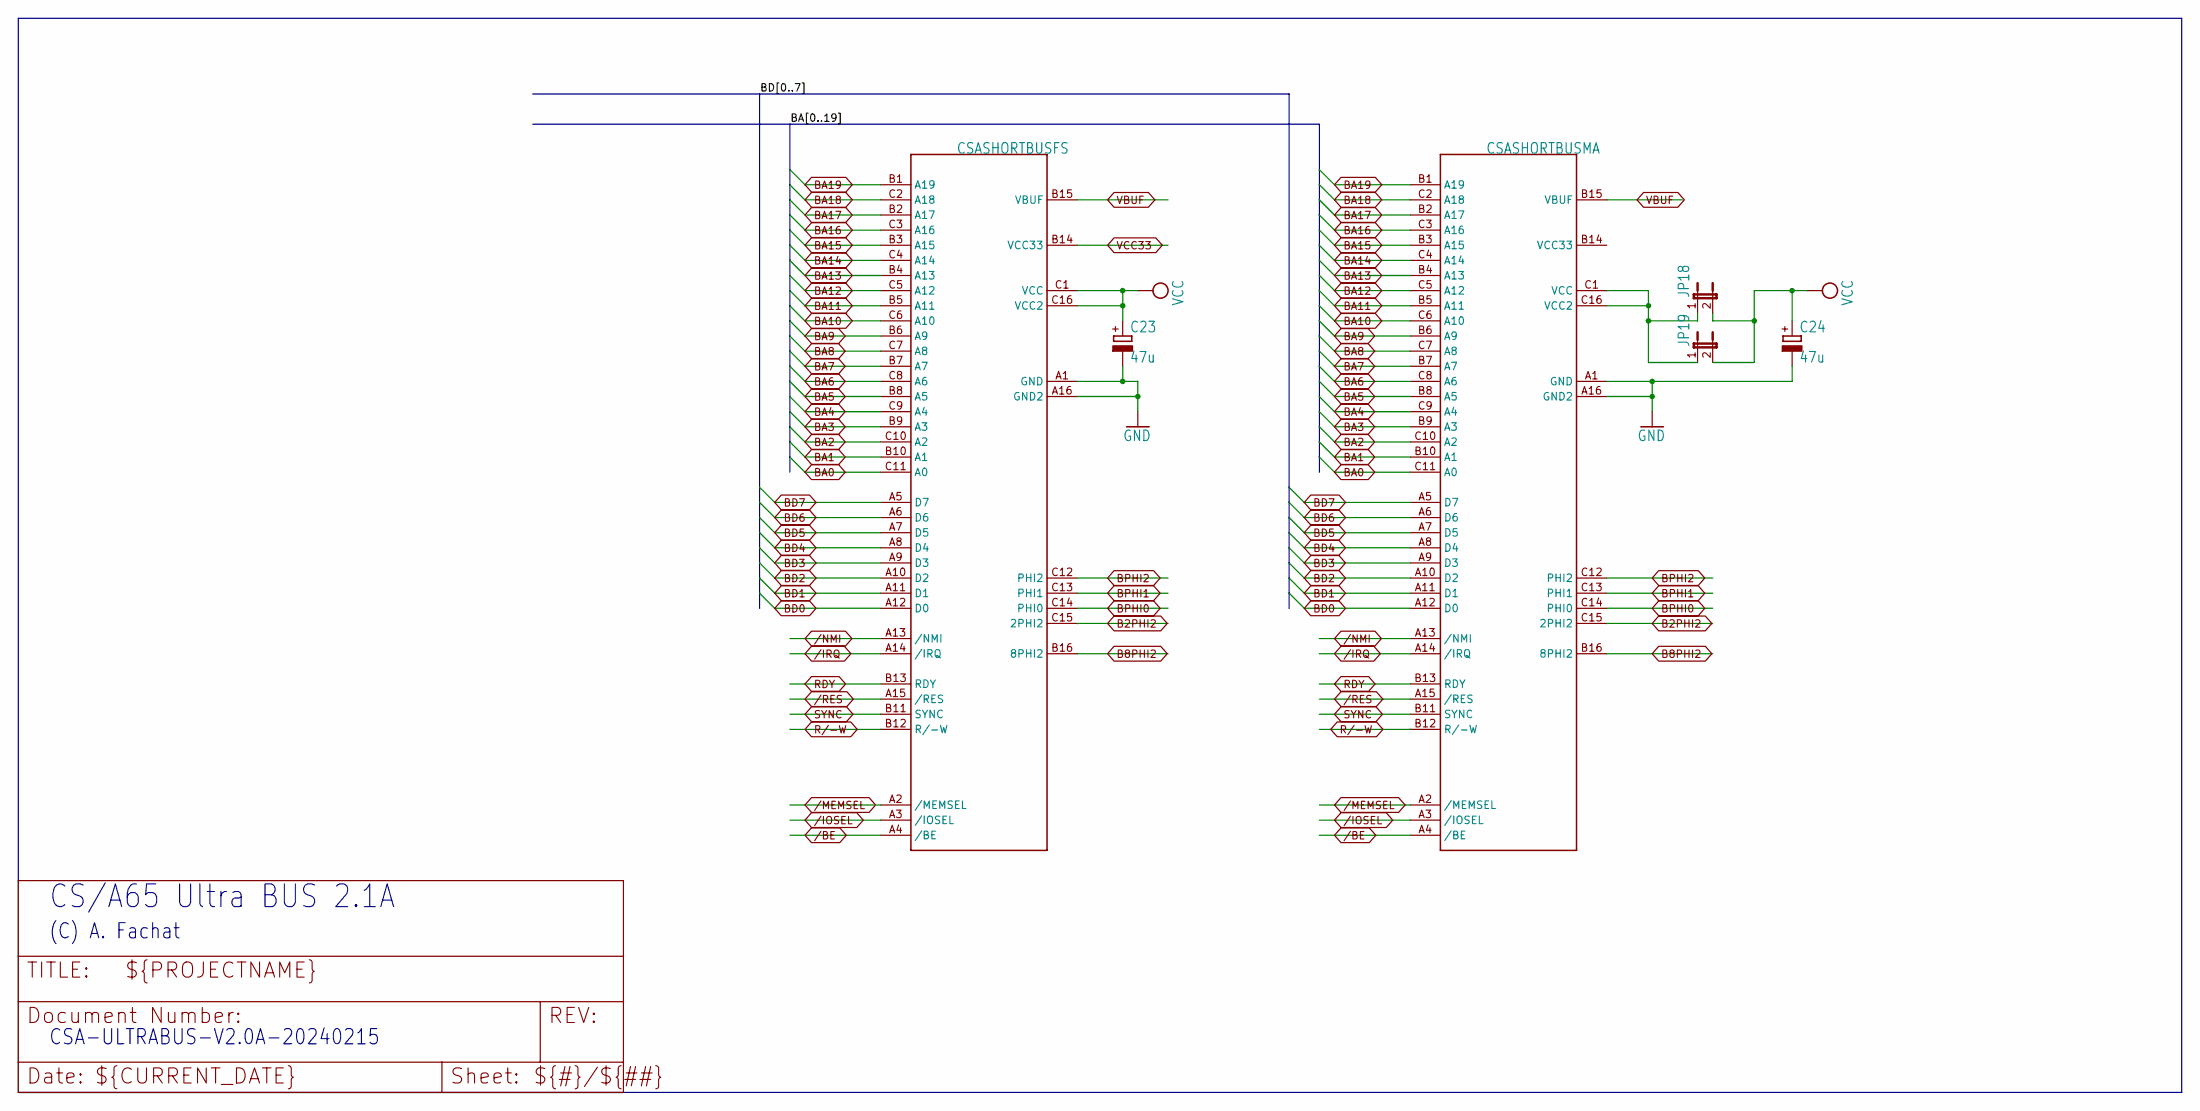
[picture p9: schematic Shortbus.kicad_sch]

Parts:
C23, C24: 47u; E2,5-5; LCSC C713185
JP18, JP19: JP1E; JP1; LCSC C7494857
U$1: CSASHORTBUSFS; FABC48S2; LCSC C5377847
U$2: CSASHORTBUSMA; MABC48B2; LCSC C5173369

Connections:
5V: C23.+, C24.+, JP18.2, JP19.2, U$1.C1 (VCC), U$1.C16 (VCC2); also elsewhere on the board
B2PHI2: U$1.C15 (2PHI2), U$2.C15 (2PHI2); also elsewhere on the board
B8PHI2: U$1.B16 (8PHI2), U$2.B16 (8PHI2); also elsewhere on the board
BA0: U$1.C11 (A0), U$2.C11 (A0); also elsewhere on the board
BA1: U$1.B10 (A1), U$2.B10 (A1); also elsewhere on the board
BA2: U$1.C10 (A2), U$2.C10 (A2); also elsewhere on the board
BA3: U$1.B9 (A3), U$2.B9 (A3); also elsewhere on the board
BA4: U$1.C9 (A4), U$2.C9 (A4); also elsewhere on the board
BA5: U$1.B8 (A5), U$2.B8 (A5); also elsewhere on the board
BA6: U$1.C8 (A6), U$2.C8 (A6); also elsewhere on the board
BA7: U$1.B7 (A7), U$2.B7 (A7); also elsewhere on the board
BA8: U$1.C7 (A8), U$2.C7 (A8); also elsewhere on the board
BA9: U$1.B6 (A9), U$2.B6 (A9); also elsewhere on the board
BA10: U$1.C6 (A10), U$2.C6 (A10); also elsewhere on the board
BA11: U$1.B5 (A11), U$2.B5 (A11); also elsewhere on the board
BA12: U$1.C5 (A12), U$2.C5 (A12); also elsewhere on the board
BA13: U$1.B4 (A13), U$2.B4 (A13); also elsewhere on the board
BA14: U$1.C4 (A14), U$2.C4 (A14); also elsewhere on the board
BA15: U$1.B3 (A15), U$2.B3 (A15); also elsewhere on the board
BA16: U$1.C3 (A16), U$2.C3 (A16); also elsewhere on the board
BA17: U$1.B2 (A17), U$2.B2 (A17); also elsewhere on the board
BA18: U$1.C2 (A18), U$2.C2 (A18); also elsewhere on the board
BA19: U$1.B1 (A19), U$2.B1 (A19); also elsewhere on the board
BD0: U$1.A12 (D0), U$2.A12 (D0); also elsewhere on the board
BD1: U$1.A11 (D1), U$2.A11 (D1); also elsewhere on the board
BD2: U$1.A10 (D2), U$2.A10 (D2); also elsewhere on the board
BD3: U$1.A9 (D3), U$2.A9 (D3); also elsewhere on the board
BD4: U$1.A8 (D4), U$2.A8 (D4); also elsewhere on the board
BD5: U$1.A7 (D5), U$2.A7 (D5); also elsewhere on the board
BD6: U$1.A6 (D6), U$2.A6 (D6); also elsewhere on the board
BD7: U$1.A5 (D7), U$2.A5 (D7); also elsewhere on the board
BPHI0: U$1.C14 (PHI0), U$2.C14 (PHI0); also elsewhere on the board
BPHI1: U$1.C13 (PHI1), U$2.C13 (PHI1); also elsewhere on the board
BPHI2: U$1.C12 (PHI2), U$2.C12 (PHI2); also elsewhere on the board
GND: C23.-, C24.-, U$1.A1 (GND), U$1.A16 (GND2), U$2.A1 (GND), U$2.A16 (GND2); also elsewhere on the board
unnamed: JP18.1, JP19.1, U$2.C1 (VCC), U$2.C16 (VCC2)
RDY: U$1.B13 (RDY), U$2.B13 (RDY); also elsewhere on the board
R/-W: U$1.B12 (R/-W), U$2.B12 (R/-W); also elsewhere on the board
SYNC: U$1.B11 (SYNC), U$2.B11 (SYNC); also elsewhere on the board
V33: U$1.B14 (VCC33); also elsewhere on the board
VBUF: U$1.B15 (VBUF), U$2.B15 (VBUF); also elsewhere on the board
/BE: U$1.A4 (/BE), U$2.A4 (/BE); also elsewhere on the board
/IOSEL: U$1.A3 (/IOSEL), U$2.A3 (/IOSEL); also elsewhere on the board
/IRQ: U$1.A14 (/IRQ), U$2.A14 (/IRQ); also elsewhere on the board
/MEMSEL: U$1.A2 (/MEMSEL), U$2.A2 (/MEMSEL); also elsewhere on the board
/NMI: U$1.A13 (/NMI), U$2.A13 (/NMI); also elsewhere on the board
/RES: U$1.A15 (/RES), U$2.A15 (/RES); also elsewhere on the board

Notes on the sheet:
(C) A. Fachat
CSA-ULTRABUS-V2.0A-20240215
CS/A65 Ultra BUS 2.1A

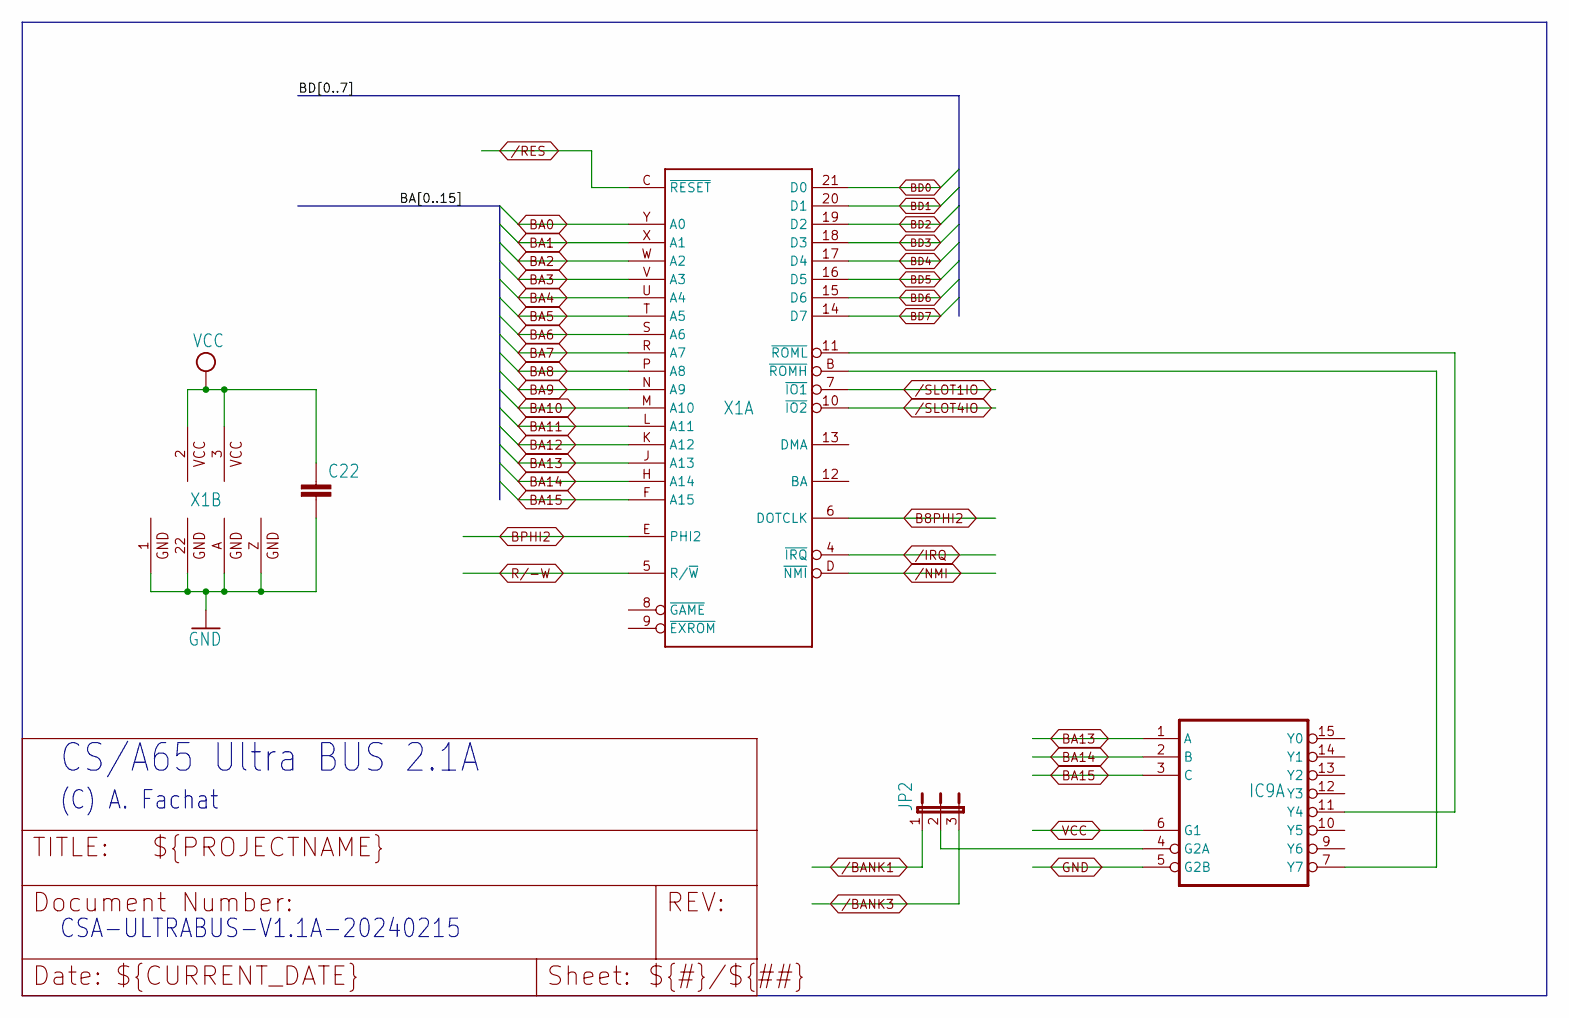
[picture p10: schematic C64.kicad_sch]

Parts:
C22: C-EUC0603; C0603; LCSC C14663
IC9: 74138D; SO16; LCSC C352958
JP2: JP2E; JP2; LCSC C6332196
X1: PORT_EXPANSION_64_CONN; FE100-22-2; LCSC C21261712

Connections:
5V: C22.1, IC9.6 (G1), X1.2 (VCC), X1.3 (VCC@1); also elsewhere on the board
B8PHI2: X1.6 (DOTCLK); also elsewhere on the board
BA0: X1.Y (A0); also elsewhere on the board
BA1: X1.X (A1); also elsewhere on the board
BA2: X1.W (A2); also elsewhere on the board
BA3: X1.V (A3); also elsewhere on the board
BA4: X1.U (A4); also elsewhere on the board
BA5: X1.T (A5); also elsewhere on the board
BA6: X1.S (A6); also elsewhere on the board
BA7: X1.R (A7); also elsewhere on the board
BA8: X1.P (A8); also elsewhere on the board
BA9: X1.N (A9); also elsewhere on the board
BA10: X1.M (A10); also elsewhere on the board
BA11: X1.L (A11); also elsewhere on the board
BA12: X1.K (A12); also elsewhere on the board
BA13: IC9.1 (A), X1.J (A13); also elsewhere on the board
BA14: IC9.2 (B), X1.H (A14); also elsewhere on the board
BA15: IC9.3 (C), X1.F (A15); also elsewhere on the board
BD0: X1.21 (D0); also elsewhere on the board
BD1: X1.20 (D1); also elsewhere on the board
BD2: X1.19 (D2); also elsewhere on the board
BD3: X1.18 (D3); also elsewhere on the board
BD4: X1.17 (D4); also elsewhere on the board
BD5: X1.16 (D5); also elsewhere on the board
BD6: X1.15 (D6); also elsewhere on the board
BD7: X1.14 (D7); also elsewhere on the board
BPHI2: X1.E (PHI2); also elsewhere on the board
GND: C22.2, IC9.5 (G2B), X1.1 (GND), X1.22 (GND@1), X1.A (GND@2), X1.Z (GND@3); also elsewhere on the board
unnamed: IC9.4 (G2A), JP2.2
unnamed: IC9.11 (Y4), X1.11 (~ROML)
unnamed: IC9.7 (Y7), X1.B (~ROMH)
R/-W: X1.5 (R/~W); also elsewhere on the board
/BANK1: JP2.1; also elsewhere on the board
/BANK3: JP2.3; also elsewhere on the board
/IRQ: X1.4 (~IRQ); also elsewhere on the board
/NMI: X1.D (~NMI); also elsewhere on the board
/RES: X1.C (~RESET); also elsewhere on the board
/SLOT1IO: X1.7 (~IO1); also elsewhere on the board
/SLOT4IO: X1.10 (~IO2); also elsewhere on the board

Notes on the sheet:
(C) A. Fachat
CS/A65 Ultra BUS 2.1A
CSA-ULTRABUS-V1.1A-20240215

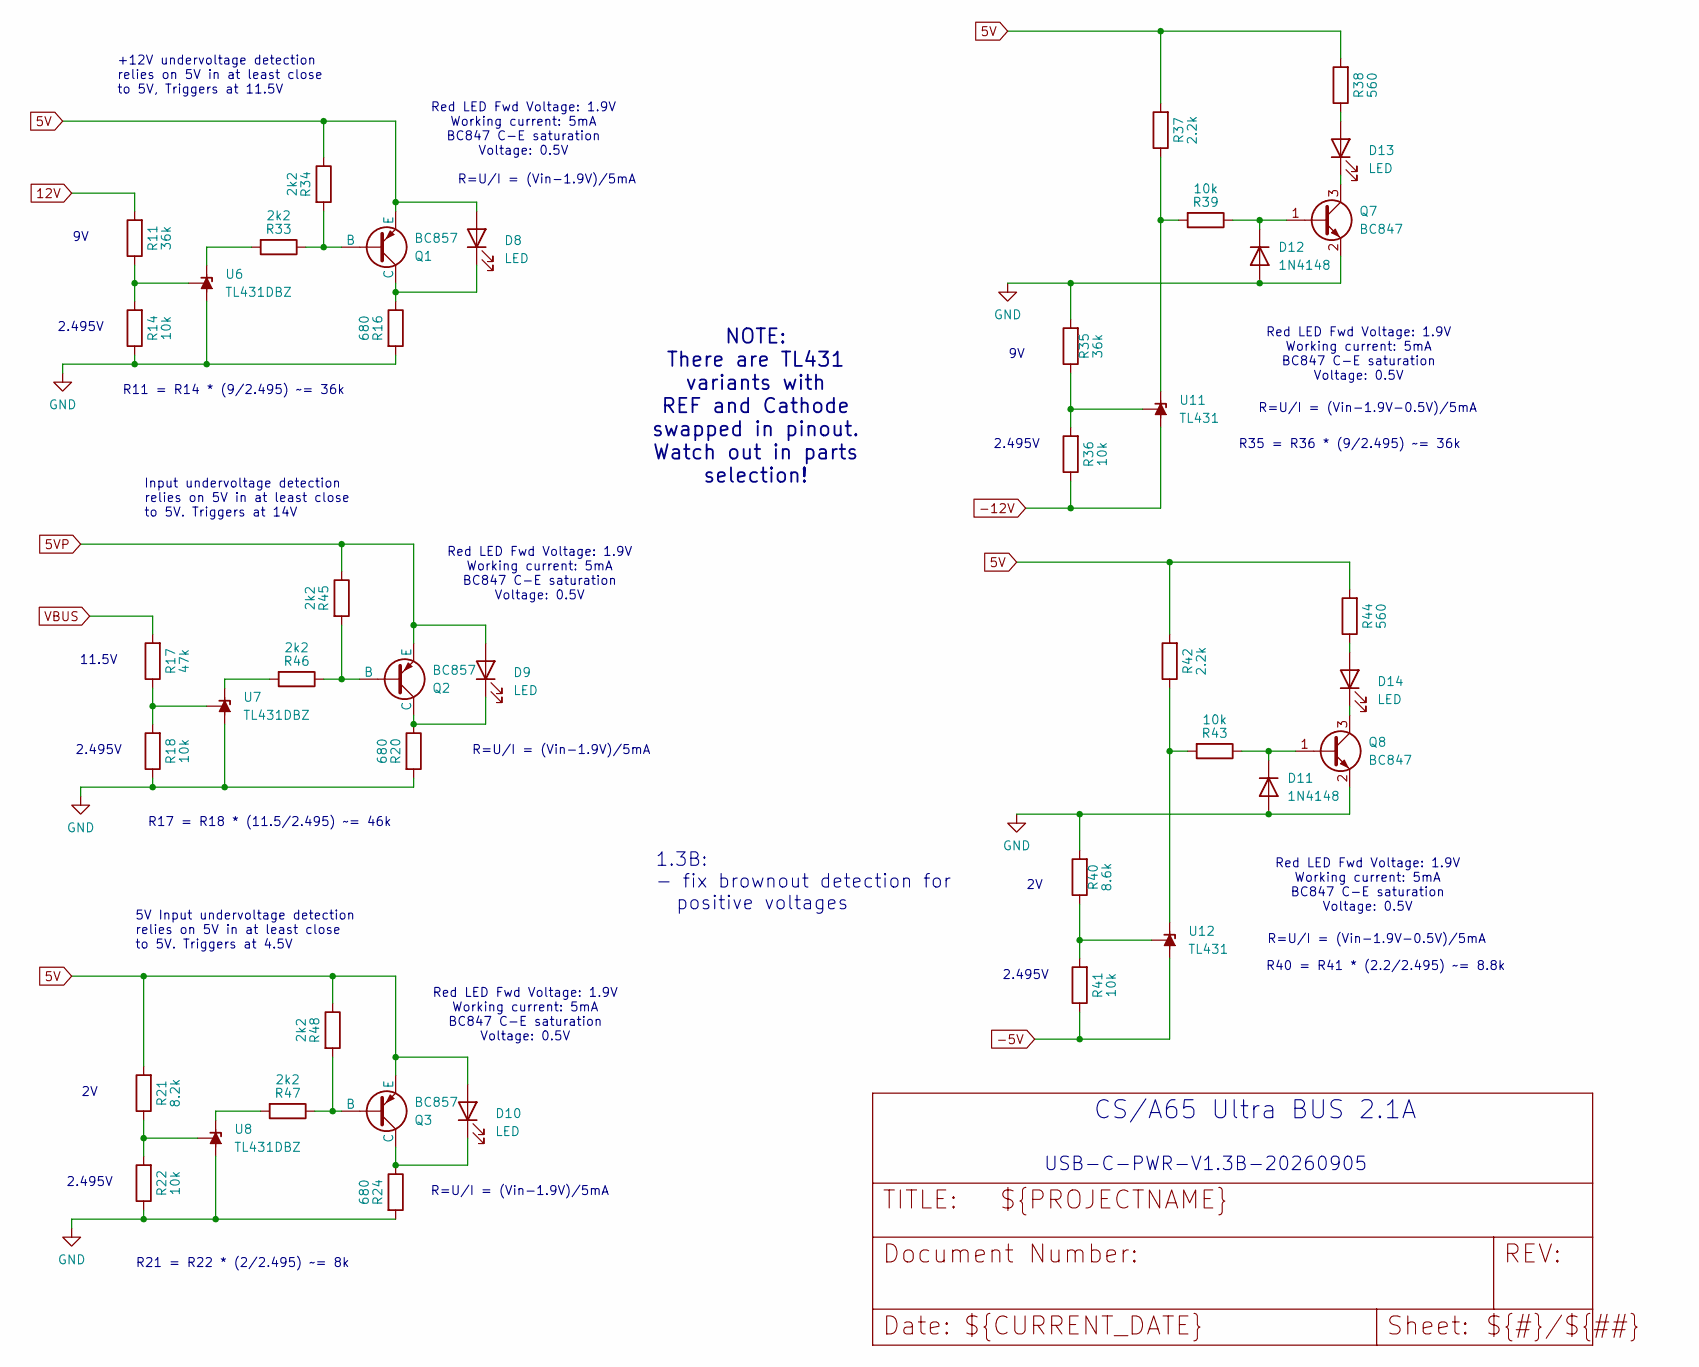
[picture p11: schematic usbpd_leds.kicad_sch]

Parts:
D8, D9, D10, D13, D14: LED; D_0603_1608Metric_Pad1.05x0.95mm_HandSolder; LCSC C7496820
D11, D12: 1N4148; D_SOD-323_HandSoldering; LCSC C2128
Q1, Q2, Q3: BC857; SOT-23; LCSC C20069137
Q7, Q8: BC847; SOT-23; LCSC C7420337
R11, R35: 36k; R_0603_1608Metric_Pad0.98x0.95mm_HandSolder; LCSC C23147
R14, R18, R22, R36, R39, R41, R43: 10k; R_0603_1608Metric_Pad0.98x0.95mm_HandSolder; LCSC C25804
R16, R20, R24: 680; R_0603_1608Metric_Pad0.98x0.95mm_HandSolder; LCSC C23228
R17: 47k; R_0603_1608Metric_Pad0.98x0.95mm_HandSolder; LCSC C25819
R21: 8.2k; R_0603_1608Metric_Pad0.98x0.95mm_HandSolder; LCSC C25981
R33, R34, R45, R46, R47, R48: 2k2; R_0603_1608Metric_Pad0.98x0.95mm_HandSolder; LCSC C4190
R37, R42: 2.2k; R_0603_1608Metric_Pad0.98x0.95mm_HandSolder; LCSC C4190
R38, R44: 560; R_0603_1608Metric_Pad0.98x0.95mm_HandSolder; LCSC C23204
R40: 8.6k; R_0603_1608Metric_Pad0.98x0.95mm_HandSolder; LCSC C2924154
U6, U7, U8: TL431DBZ; SOT-23; LCSC C181103
U11, U12: TL431; SOT-23; LCSC C181103

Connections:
5V: D8.2 (A), D10.2 (A), Q1.2 (E), Q3.2 (E), R21.2, R34.1, R37.2, R38.2, R42.2, R44.2, R48.1; also elsewhere on the board
5VP: D9.2 (A), Q2.2 (E), R45.1; also elsewhere on the board
12V: R11.2; also elsewhere on the board
-5V: R41.1, U12.3 (A); also elsewhere on the board
-12V: R36.1, U11.3 (A); also elsewhere on the board
GND: D11.2 (A), D12.2 (A), Q7.2 (E), Q8.2 (E), R14.1, R16.2, R18.1, R20.2, R22.1, R24.2, R35.2, R40.2, U6.3 (A), U7.3 (A), U8.3 (A); also elsewhere on the board
unnamed: D8.1 (K), Q1.3 (C), R16.1
unnamed: D9.1 (K), Q2.3 (C), R20.1
unnamed: D10.1 (K), Q3.3 (C), R24.1
unnamed: D11.1 (K), Q8.1 (B), R43.1
unnamed: D12.1 (K), Q7.1 (B), R39.1
unnamed: D13.2 (A), R38.1
unnamed: D13.1 (K), Q7.3 (C)
unnamed: D14.2 (A), R44.1
unnamed: D14.1 (K), Q8.3 (C)
unnamed: Q1.1 (B), R33.1, R34.2
unnamed: Q2.1 (B), R45.2, R46.1
unnamed: Q3.1 (B), R47.1, R48.2
unnamed: R33.2, U6.2 (K)
unnamed: R11.1, R14.2, U6.1 (REF)
unnamed: R46.2, U7.2 (K)
unnamed: R17.1, R18.2, U7.1 (REF)
unnamed: R47.2, U8.2 (K)
unnamed: R21.1, R22.2, U8.1 (REF)
unnamed: R37.1, R39.2, U11.2 (K)
unnamed: R35.1, R36.2, U11.1 (REF)
unnamed: R42.1, R43.2, U12.2 (K)
unnamed: R40.1, R41.2, U12.1 (REF)
VBUS: R17.2; also elsewhere on the board

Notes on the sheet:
Input undervoltage detection relies on 5V in at least close to 5V. Triggers at 14V
Red LED Fwd Voltage: 1.9V Working current: 5mA BC847 C-E saturation Voltage: 0.5V
2.495V
R21 = R22 * (2/2.495) ~= 8k
R=U/I = (Vin-1.9V-0.5V)/5mA
R=U/I = (Vin-1.9V)/5mA
11.5V
CS/A65 Ultra BUS 2.1A
+12V undervoltage detection relies on 5V in at least close to 5V, Triggers at 11.5V
NOTE: There are TL431 variants with REF and Cathode swapped in pinout. Watch out in parts selection!
5V Input undervoltage detection relies on 5V in at least close to 5V. Triggers at 4.5V
R11 = R14 * (9/2.495) ~= 36k
1.3B: - fix brownout detection for positive voltages
USB-C-PWR-V1.3B-20260905
R17 = R18 * (11.5/2.495) ~= 46k
R40 = R41 * (2.2/2.495) ~= 8.8k
R35 = R36 * (9/2.495) ~= 36k

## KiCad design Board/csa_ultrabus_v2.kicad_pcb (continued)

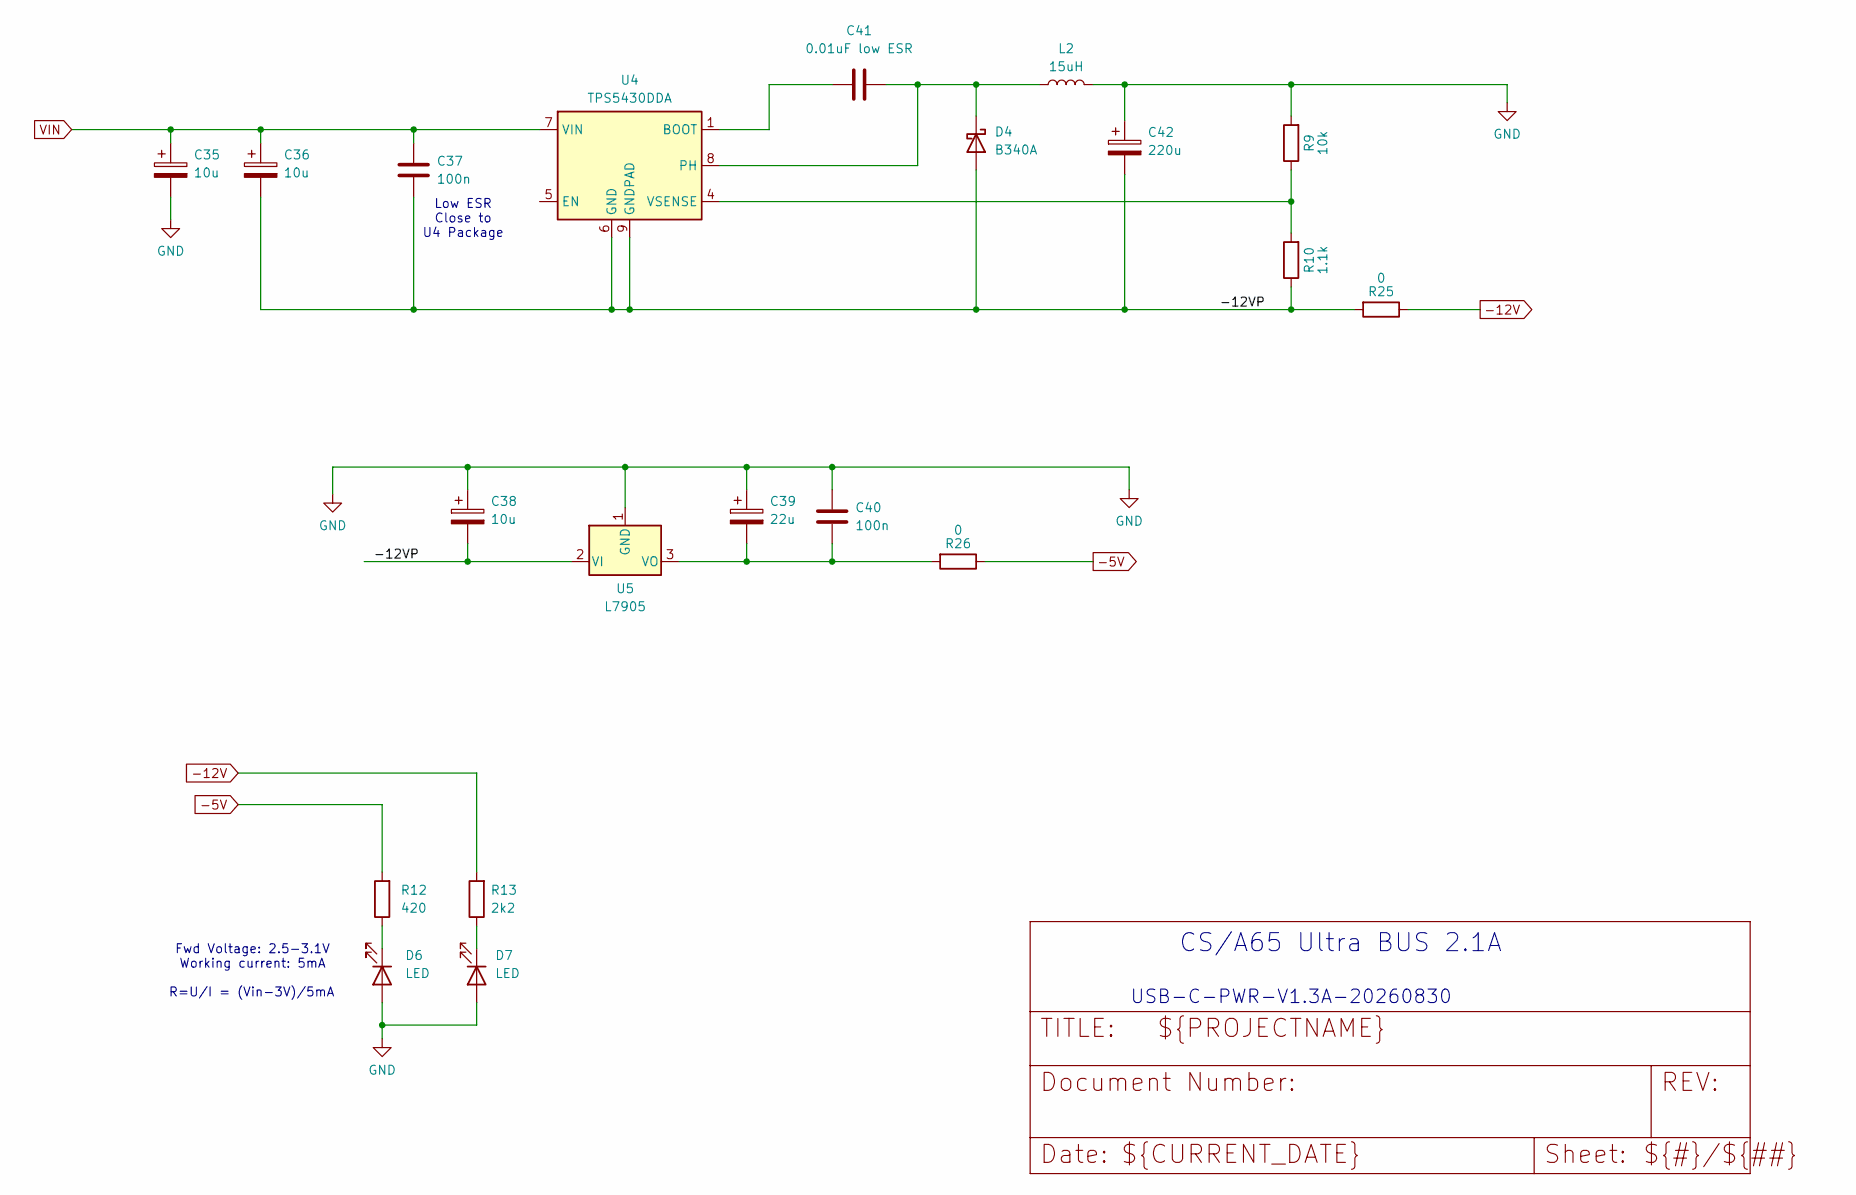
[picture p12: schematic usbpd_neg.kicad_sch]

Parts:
C35, C36, C38: 10u; C_1206_3216Metric_Pad1.33x1.80mm_HandSolder; LCSC C33546014
C37, C40: 100n; C_0603_1608Metric_Pad1.08x0.95mm_HandSolder; LCSC C14663
C39: 22u; C_1206_3216Metric_Pad1.33x1.80mm_HandSolder; LCSC C12891
C41: 0.01uF low ESR; C_0603_1608Metric_Pad1.08x0.95mm_HandSolder; LCSC C57112
C42: 220u; CP_Elec_10x10; LCSC C125977
D4: B340A; D_SMA_Handsoldering; LCSC C3018525
D6, D7: LED; D_0603_1608Metric_Pad1.05x0.95mm_HandSolder; LCSC C12065
L2: 15uH; L_APV_APH0630; LCSC C5189959
R9: 10k; R_0603_1608Metric_Pad0.98x0.95mm_HandSolder; LCSC C25804
R10: 1.1k; R_0603_1608Metric_Pad0.98x0.95mm_HandSolder; LCSC C22764
R12: 420; R_0603_1608Metric_Pad0.98x0.95mm_HandSolder; LCSC C23057
R13: 2k2; R_0603_1608Metric_Pad0.98x0.95mm_HandSolder; LCSC C4190
R25, R26: 0; R_0603_1608Metric_Pad0.98x0.95mm_HandSolder; LCSC C21189
U4: TPS5430DDA; TI_SO-PowerPAD-8_ThermalVias; LCSC C9864
U5: L7905; TO-252-3_TabPin2; LCSC C962758

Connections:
-5V: R12.2, R26.1; also elsewhere on the board
-12V: R13.2, R25.1; also elsewhere on the board
/usbpd negative voltages/-12VP: C36.2, C37.2, C38.2, C42.2, D4.2 (A), R10.1, R25.2, U4.6 (GND), U4.9 (GNDPAD), U5.2 (VI)
GND: C35.2, C38.1, C39.1, C40.2, C42.1, D6.2 (A), D7.2 (A), L2.2, R9.2, U5.1 (GND); also elsewhere on the board
unnamed: C41.2, D4.1 (K), L2.1, U4.8 (PH)
unnamed: D6.1 (K), R12.1
unnamed: D7.1 (K), R13.1
unnamed: C41.1, U4.1 (BOOT)
unnamed: R9.1, R10.2, U4.4 (VSENSE)
unnamed: C39.2, C40.1, R26.2, U5.3 (VO)
VBUS: C35.1, C36.1, C37.1, U4.7 (VIN); also elsewhere on the board

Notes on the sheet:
Low ESR Close to U4 Package
R=U/I = (Vin-3V)/5mA
USB-C-PWR-V1.3A-20260830
Fwd Voltage: 2.5-3.1V Working current: 5mA
CS/A65 Ultra BUS 2.1A

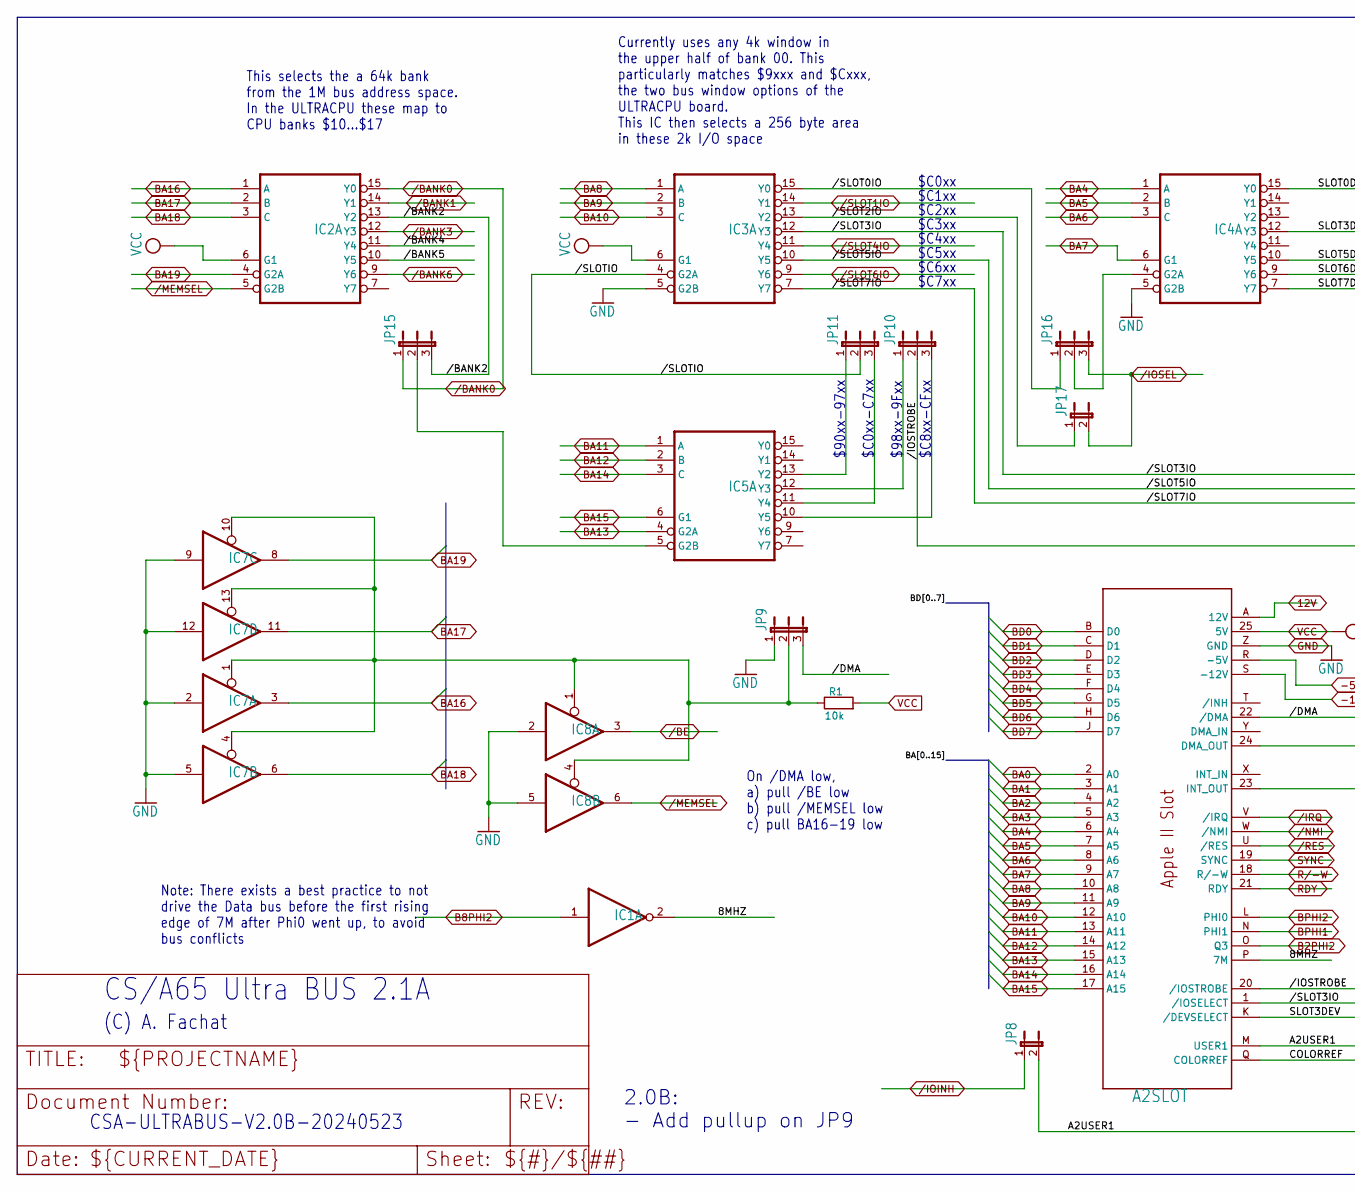
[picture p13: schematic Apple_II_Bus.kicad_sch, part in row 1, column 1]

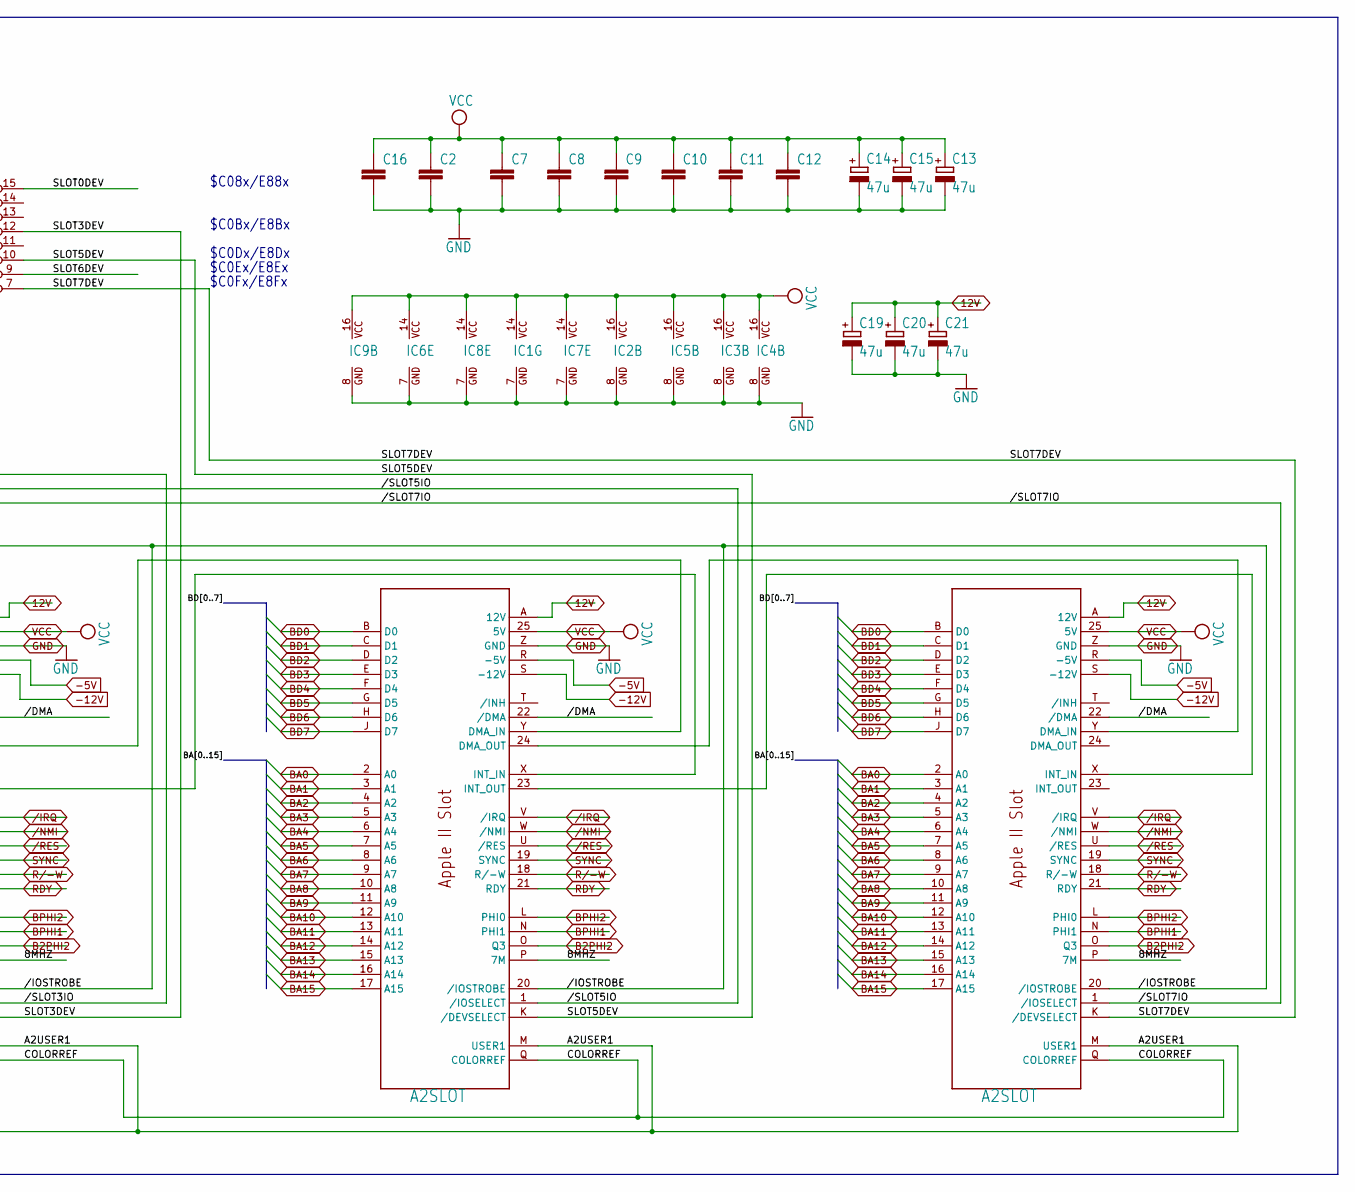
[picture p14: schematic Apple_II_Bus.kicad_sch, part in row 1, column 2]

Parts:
C2, C7, C8, C9, C10, C11, C12, C16: C-EUC0603; C0603; LCSC C14663
C13, C14, C15, C19, C20, C21: 47u; E2,5-5; LCSC C713185
IC1: 7404D; SO14; LCSC C6766
IC2, IC3, IC4, IC5, IC9: 74138D; SO16; LCSC C352958
IC6: 7400D; SO14; LCSC C282337
IC7, IC8: 74125D; SO14; LCSC C5962
JP8, JP17: JP1E; JP1; LCSC C7494857
JP9, JP10, JP11, JP15, JP16: JP2E; JP2; LCSC C6332196
R1: 10k; R_0603_1608Metric_Pad0.98x0.95mm_HandSolder; LCSC C25804
SLOT3, SLOT5, SLOT7: A2SLOT; FE100-25; LCSC C5173308

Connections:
5V: C2.1, C7.1, C8.1, C9.1, C10.1, C11.1, C12.1, C13.+, C14.+, C15.+, C16.1, IC1.14 (VCC), IC2.6 (G1), IC2.16 (VCC), IC3.6 (G1), IC3.16 (VCC), IC4.16 (VCC), IC5.16 (VCC), IC6.14 (VCC), IC7.14 (VCC), IC8.14 (VCC), IC9.16 (VCC), R1.2, SLOT3.25 (5V), SLOT5.25 (5V), SLOT7.25 (5V); also elsewhere on the board
12V: C19.+, C20.+, C21.+, SLOT3.A (12V), SLOT5.A (12V), SLOT7.A (12V); also elsewhere on the board
-5V: SLOT3.R (-5V), SLOT5.R (-5V), SLOT7.R (-5V); also elsewhere on the board
-12V: SLOT3.S (-12V), SLOT5.S (-12V), SLOT7.S (-12V); also elsewhere on the board
/Apple II Bus/8MHZ: IC1.2 (O), SLOT3.P (7M), SLOT5.P (7M), SLOT7.P (7M)
/Apple II Bus/A2USER1: JP8.2, SLOT3.M (USER1), SLOT5.M (USER1), SLOT7.M (USER1)
/Apple II Bus/COLORREF: SLOT3.Q (COLORREF), SLOT5.Q (COLORREF), SLOT7.Q (COLORREF)
/Apple II Bus/SLOT0DEV: IC4.15 (Y0)
/Apple II Bus/SLOT3DEV: IC4.12 (Y3), SLOT3.K (/DEVSELECT)
/Apple II Bus/SLOT5DEV: IC4.10 (Y5), SLOT5.K (/DEVSELECT)
/Apple II Bus/SLOT6DEV: IC4.9 (Y6)
/Apple II Bus/SLOT7DEV: IC4.7 (Y7), SLOT7.K (/DEVSELECT)
/Apple II Bus//BANK2: IC2.13 (Y2), JP15.3
/Apple II Bus//BANK4: IC2.11 (Y4)
/Apple II Bus//BANK5: IC2.10 (Y5)
/Apple II Bus//DMA: JP9.3, SLOT3.22 (/DMA), SLOT5.22 (/DMA), SLOT7.22 (/DMA)
/Apple II Bus//IOSTROBE: JP10.2, SLOT3.20 (/IOSTROBE), SLOT5.20 (/IOSTROBE), SLOT7.20 (/IOSTROBE)
/Apple II Bus//SLOT0IO: IC3.15 (Y0), JP16.1
/Apple II Bus//SLOT2IO: IC3.13 (Y2), JP17.1
/Apple II Bus//SLOT3IO: IC3.12 (Y3), SLOT3.1 (/IOSELECT)
/Apple II Bus//SLOT5IO: IC3.10 (Y5), SLOT5.1 (/IOSELECT)
/Apple II Bus//SLOT7IO: IC3.7 (Y7), SLOT7.1 (/IOSELECT)
/Apple II Bus//SLOTIO: IC3.4 (G2A), JP11.2
B2PHI2: SLOT3.O (Q3), SLOT5.O (Q3), SLOT7.O (Q3); also elsewhere on the board
B8PHI2: IC1.1 (I); also elsewhere on the board
BA0: SLOT3.2 (A0), SLOT5.2 (A0), SLOT7.2 (A0); also elsewhere on the board
BA1: SLOT3.3 (A1), SLOT5.3 (A1), SLOT7.3 (A1); also elsewhere on the board
BA2: SLOT3.4 (A2), SLOT5.4 (A2), SLOT7.4 (A2); also elsewhere on the board
BA3: SLOT3.5 (A3), SLOT5.5 (A3), SLOT7.5 (A3); also elsewhere on the board
BA4: IC4.1 (A), SLOT3.6 (A4), SLOT5.6 (A4), SLOT7.6 (A4); also elsewhere on the board
BA5: IC4.2 (B), SLOT3.7 (A5), SLOT5.7 (A5), SLOT7.7 (A5); also elsewhere on the board
BA6: IC4.3 (C), SLOT3.8 (A6), SLOT5.8 (A6), SLOT7.8 (A6); also elsewhere on the board
BA7: IC4.6 (G1), SLOT3.9 (A7), SLOT5.9 (A7), SLOT7.9 (A7); also elsewhere on the board
BA8: IC3.1 (A), SLOT3.10 (A8), SLOT5.10 (A8), SLOT7.10 (A8); also elsewhere on the board
BA9: IC3.2 (B), SLOT3.11 (A9), SLOT5.11 (A9), SLOT7.11 (A9); also elsewhere on the board
BA10: IC3.3 (C), SLOT3.12 (A10), SLOT5.12 (A10), SLOT7.12 (A10); also elsewhere on the board
BA11: IC5.1 (A), SLOT3.13 (A11), SLOT5.13 (A11), SLOT7.13 (A11); also elsewhere on the board
BA12: IC5.2 (B), SLOT3.14 (A12), SLOT5.14 (A12), SLOT7.14 (A12); also elsewhere on the board
BA13: IC5.4 (G2A), SLOT3.15 (A13), SLOT5.15 (A13), SLOT7.15 (A13); also elsewhere on the board
BA14: IC5.3 (C), SLOT3.16 (A14), SLOT5.16 (A14), SLOT7.16 (A14); also elsewhere on the board
BA15: IC5.6 (G1), SLOT3.17 (A15), SLOT5.17 (A15), SLOT7.17 (A15); also elsewhere on the board
BA16: IC2.1 (A), IC7.3 (O); also elsewhere on the board
BA17: IC2.2 (B), IC7.11 (O); also elsewhere on the board
BA18: IC2.3 (C), IC7.6 (O); also elsewhere on the board
BA19: IC2.4 (G2A), IC7.8 (O); also elsewhere on the board
BD0: SLOT3.B (D0), SLOT5.B (D0), SLOT7.B (D0); also elsewhere on the board
BD1: SLOT3.C (D1), SLOT5.C (D1), SLOT7.C (D1); also elsewhere on the board
BD2: SLOT3.D (D2), SLOT5.D (D2), SLOT7.D (D2); also elsewhere on the board
BD3: SLOT3.E (D3), SLOT5.E (D3), SLOT7.E (D3); also elsewhere on the board
BD4: SLOT3.F (D4), SLOT5.F (D4), SLOT7.F (D4); also elsewhere on the board
BD5: SLOT3.G (D5), SLOT5.G (D5), SLOT7.G (D5); also elsewhere on the board
BD6: SLOT3.H (D6), SLOT5.H (D6), SLOT7.H (D6); also elsewhere on the board
BD7: SLOT3.J (D7), SLOT5.J (D7), SLOT7.J (D7); also elsewhere on the board
BPHI1: SLOT3.N (PHI1), SLOT5.N (PHI1), SLOT7.N (PHI1); also elsewhere on the board
BPHI2: SLOT3.L (PHI0), SLOT5.L (PHI0), SLOT7.L (PHI0); also elsewhere on the board
GND: C2.2, C7.2, C8.2, C9.2, C10.2, C11.2, C12.2, C13.-, C14.-, C15.-, C16.2, C19.-, C20.-, C21.-, IC1.7 (GND), IC2.8 (GND), IC3.5 (G2B), IC3.8 (GND), IC4.5 (G2B), IC4.8 (GND), IC5.8 (GND), IC6.7 (GND), IC7.2 (I), IC7.5 (I), IC7.7 (GND), IC7.9 (I), IC7.12 (I), IC8.2 (I), IC8.5 (I), IC8.7 (GND), IC9.8 (GND), JP9.1, SLOT3.Z (GND), SLOT5.Z (GND), SLOT7.Z (GND); also elsewhere on the board
unnamed: IC4.4 (G2A), JP16.2
unnamed: IC5.5 (G2B), JP15.2
unnamed: IC5.13 (Y2), JP11.1
unnamed: IC5.12 (Y3), JP10.1
unnamed: IC5.11 (Y4), JP11.3
unnamed: IC5.10 (Y5), JP10.3
unnamed: IC7.1 (OE), IC7.4 (OE), IC7.10 (OE), IC7.13 (OE), IC8.1 (OE), IC8.4 (OE), JP9.2, R1.1
unnamed: SLOT3.24 (DMA_OUT), SLOT5.Y (DMA_IN)
unnamed: SLOT3.23 (INT_OUT), SLOT5.X (INT_IN)
unnamed: SLOT5.24 (DMA_OUT), SLOT7.Y (DMA_IN)
unnamed: SLOT5.23 (INT_OUT), SLOT7.X (INT_IN)
RDY: SLOT3.21 (RDY), SLOT5.21 (RDY), SLOT7.21 (RDY); also elsewhere on the board
R/-W: SLOT3.18 (R/-W), SLOT5.18 (R/-W), SLOT7.18 (R/-W); also elsewhere on the board
SYNC: SLOT3.19 (SYNC), SLOT5.19 (SYNC), SLOT7.19 (SYNC); also elsewhere on the board
/BANK0: IC2.15 (Y0), JP15.1; also elsewhere on the board
/BANK1: IC2.14 (Y1); also elsewhere on the board
/BANK3: IC2.12 (Y3); also elsewhere on the board
/BANK6: IC2.9 (Y6); also elsewhere on the board
/BE: IC8.3 (O); also elsewhere on the board
/IOINH: JP8.1; also elsewhere on the board
/IOSEL: JP16.3, JP17.2; also elsewhere on the board
/IRQ: SLOT3.V (/IRQ), SLOT5.V (/IRQ), SLOT7.V (/IRQ); also elsewhere on the board
/MEMSEL: IC2.5 (G2B), IC8.6 (O); also elsewhere on the board
/NMI: SLOT3.W (/NMI), SLOT5.W (/NMI), SLOT7.W (/NMI); also elsewhere on the board
/RES: SLOT3.U (/RES), SLOT5.U (/RES), SLOT7.U (/RES); also elsewhere on the board
/SLOT1IO: IC3.14 (Y1); also elsewhere on the board
/SLOT4IO: IC3.11 (Y4); also elsewhere on the board
/SLOT6IO: IC3.9 (Y6); also elsewhere on the board

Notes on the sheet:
$C7xx
2.0B: - Add pullup on JP9
$C3xx
$90xx-97xx
Currently uses any 4k window in the upper half of bank 00. This particularly matches $9xxx and $Cxxx, the two bus window options of the ULTRACPU board. This IC then selects a 256 byte area in these 2k I/O space
$C5xx
CS/A65 Ultra BUS 2.1A
This selects the a 64k bank from the 1M bus address space. In the ULTRACPU these map to CPU banks $10...$17
$C0xx-C7xx
$C0Dx/E8Dx
On /DMA low, a) pull /BE low b) pull /MEMSEL low c) pull BA16-19 low
$C0Bx/E8Bx
CSA-ULTRABUS-V2.0B-20240523
$C4xx
Note: There exists a best practice to not drive the Data bus before the first rising edge of 7M after Phi0 went up, to avoid bus conflicts
$C8xx-CFxx
$C08x/E88x
$C0Ex/E8Ex
$98xx-9Fxx
(C) A. Fachat
$C0xx
$C1xx
$C2xx
$C0Fx/E8Fx
$C6xx

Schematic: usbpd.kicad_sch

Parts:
C25: 100n; C_0603_1608Metric_Pad1.08x0.95mm_HandSolder; LCSC C14663
C26: 1u; C_1206_3216Metric_Pad1.33x1.80mm_HandSolder; LCSC C1848
C27: 10u; C_1206_3216Metric_Pad1.33x1.80mm_HandSolder; LCSC C33546014
J3: USB_C_Receptacle_USB2.0_16P; USB_C_Receptacle_GCT_USB4105-xx-A_16P_TopMnt_Horizontal; LCSC C2765186
JP3: Jumper_2_Open; SolderJumper-2_P1.3mm_Open_RoundedPad1.0x1.5mm
R7: 5.1k; R_0603_1608Metric_Pad0.98x0.95mm_HandSolder; LCSC C23186
R29: 1k, >=0.3W; R_0603_1608Metric_Pad0.98x0.95mm_HandSolder; LCSC C5886053
R30: 10k; R_0603_1608Metric_Pad0.98x0.95mm_HandSolder; LCSC C25804
U9: CH224K; SSOP-10-1EP_3.9x4.9mm_P1mm_EP2.1x3.3mm; LCSC C970725

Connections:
GND: C25.2, C26.2, C27.2, J3.A1 (GND), J3.A12 (GND), J3.B1 (GND), J3.B12 (GND), R7.2, U9.9 (CFG1), U9.11 (GND); also elsewhere on the board
unnamed: J3.A5 (CC1), U9.7 (CC1)
unnamed: J3.B5 (CC2), U9.6 (CC2)
unnamed: C25.1, J3.SH (SHIELD), R7.1
unnamed: JP3.1 (A), U9.3 (CFG3)
unnamed: C26.1, JP3.2 (B), R29.2, U9.1 (VDD), U9.2 (CFG2)
unnamed: J3.A7 (D-), J3.B7 (D-), U9.5 (DM)
unnamed: J3.A6 (D+), J3.B6 (D+), U9.4 (DP)
unnamed: R30.2, U9.8 (VBUS)
VBUS: C27.1, J3.A4 (VBUS), J3.A9 (VBUS), J3.B4 (VBUS), J3.B9 (VBUS), R29.1, R30.1; also elsewhere on the board

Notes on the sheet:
USB-C Power Delivery Controller to get 15V 2A or 20V 3A
TYPE-C 16PIN 2MD(073)
USB-C-PWR-V1.3A-20260830
CS/A65 Ultra BUS 2.1A
Open = 20V Close = 15V

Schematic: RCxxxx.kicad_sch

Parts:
IC1: 7404D; SO14; LCSC C6766
IC6: 7400D; SO14; LCSC C282337
JP14: JP2E; JP2; LCSC C6332196
SLOT6.1, SLOT6.2: RC2014/6502; SIL40; LCSC C18078141

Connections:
5V: SLOT6.1.18 (VCC), SLOT6.2.18 (VCC); also elsewhere on the board
/RCxxxx/N$1: IC1.11 (I), JP14.2
/RCxxxx/RC_CLK: SLOT6.1.21 (PHI0,CLK), SLOT6.2.21 (PHI0,CLK)
/RCxxxx/RX: SLOT6.1.36 (RX), SLOT6.2.36 (RX)
/RCxxxx/TX: SLOT6.1.35 (TX), SLOT6.2.35 (TX)
/RCxxxx/USER1: SLOT6.1.37 (*/NMI,USER1), SLOT6.2.37 (*/NMI,USER1)
/RCxxxx/USER2: SLOT6.1.38 (EX1/USER2), SLOT6.2.38 (EX1/USER2)
/RCxxxx/USER3: SLOT6.1.39 (EX2/USER3), SLOT6.2.39 (EX2/USER3)
/RCxxxx/USER4: SLOT6.1.40 (USER4), SLOT6.2.40 (USER4)
/RCxxxx//M1: IC1.4 (O), SLOT6.1.19 (*PHI2,/M1), SLOT6.2.19 (*PHI2,/M1)
/RCxxxx//RD0: IC6.6 (O), SLOT6.1.25 (*RDY,/RD), SLOT6.2.25 (*RDY,/RD)
/RCxxxx//SLOT6.X_BANK: IC6.8 (O), SLOT6.1.23 (*PHI1,/MREQ), SLOT6.2.23 (*PHI1,/MREQ)
/RCxxxx//SLOT6.X_IO: IC6.11 (O), SLOT6.1.26 (*SYNC,/IOREQ), SLOT6.2.26 (*SYNC,/IOREQ)
/RCxxxx//WR0: IC6.3 (O), SLOT6.1.24 (*R/-W,/WR), SLOT6.2.24 (*R/-W,/WR)
BA0: SLOT6.1.16 (A0), SLOT6.2.16 (A0); also elsewhere on the board
BA1: SLOT6.1.15 (A1), SLOT6.2.15 (A1); also elsewhere on the board
BA2: SLOT6.1.14 (A2), SLOT6.2.14 (A2); also elsewhere on the board
BA3: SLOT6.1.13 (A3), SLOT6.2.13 (A3); also elsewhere on the board
BA4: SLOT6.1.12 (A4), SLOT6.2.12 (A4); also elsewhere on the board
BA5: SLOT6.1.11 (A5), SLOT6.2.11 (A5); also elsewhere on the board
BA6: SLOT6.1.10 (A6), SLOT6.2.10 (A6); also elsewhere on the board
BA7: SLOT6.1.9 (A7), SLOT6.2.9 (A7); also elsewhere on the board
BA8: SLOT6.1.8 (A8), SLOT6.2.8 (A8); also elsewhere on the board
BA9: SLOT6.1.7 (A9), SLOT6.2.7 (A9); also elsewhere on the board
BA10: SLOT6.1.6 (A10), SLOT6.2.6 (A10); also elsewhere on the board
BA11: SLOT6.1.5 (A11), SLOT6.2.5 (A11); also elsewhere on the board
BA12: SLOT6.1.4 (A12), SLOT6.2.4 (A12); also elsewhere on the board
BA13: SLOT6.1.3 (A13), SLOT6.2.3 (A13); also elsewhere on the board
BA14: SLOT6.1.2 (A14), SLOT6.2.2 (A14); also elsewhere on the board
BA15: SLOT6.1.1 (A15), SLOT6.2.1 (A15); also elsewhere on the board
BD0: SLOT6.1.27 (D0), SLOT6.2.27 (D0); also elsewhere on the board
BD1: SLOT6.1.28 (D1), SLOT6.2.28 (D1); also elsewhere on the board
BD2: SLOT6.1.29 (D2), SLOT6.2.29 (D2); also elsewhere on the board
BD3: SLOT6.1.30 (D3), SLOT6.2.30 (D3); also elsewhere on the board
BD4: SLOT6.1.31 (D4), SLOT6.2.31 (D4); also elsewhere on the board
BD5: SLOT6.1.32 (D5), SLOT6.2.32 (D5); also elsewhere on the board
BD6: SLOT6.1.33 (D6), SLOT6.2.33 (D6); also elsewhere on the board
BD7: SLOT6.1.34 (D7), SLOT6.2.34 (D7); also elsewhere on the board
BPHI2: IC6.2 (I1), IC6.4 (I0), IC6.9 (I0), IC6.12 (I0); also elsewhere on the board
GND: SLOT6.1.17 (GND), SLOT6.2.17 (GND); also elsewhere on the board
unnamed: IC1.6 (O), IC6.1 (I0)
unnamed: IC1.8 (O), IC6.13 (I1)
unnamed: IC1.10 (O), IC6.10 (I1)
R/-W: IC1.5 (I), IC6.5 (I1); also elsewhere on the board
SYNC: IC1.3 (I); also elsewhere on the board
/BANK0: JP14.1; also elsewhere on the board
/BANK6: JP14.3; also elsewhere on the board
/IRQ: SLOT6.1.22 (/IRQ), SLOT6.2.22 (/IRQ); also elsewhere on the board
/RES: SLOT6.1.20 (/RES), SLOT6.2.20 (/RES); also elsewhere on the board
/SLOT6IO: IC1.9 (I); also elsewhere on the board

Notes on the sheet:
(C) A. Fachat
CS/A65 Ultra BUS 2.1A
1.0B: - fix qualifying SLOTIO and BANK with Phi2 - separate RC_CLK from BPHI0 1.1A: - remove RC6502 slot - Both remaining RC2014 now have MREQ and IOREQ qualified with Phi2
CSA-ULTRABUS-V1.1A-20240215

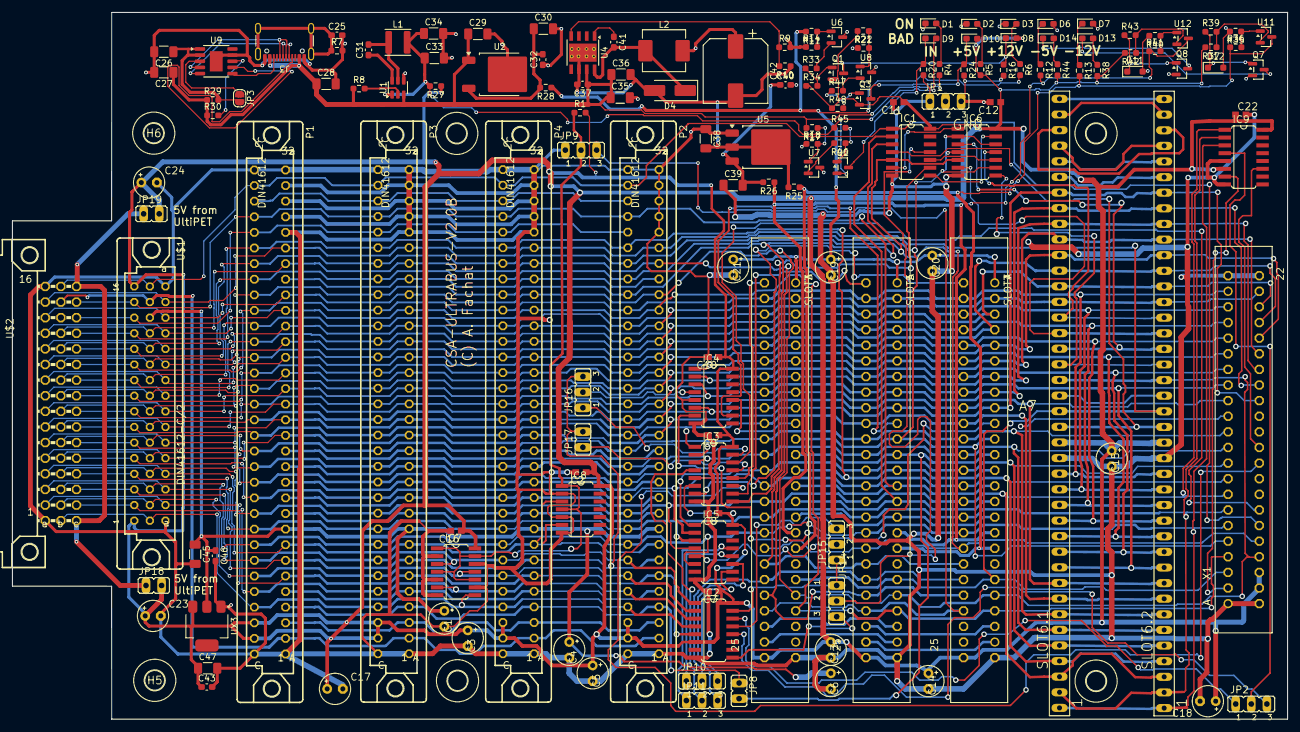
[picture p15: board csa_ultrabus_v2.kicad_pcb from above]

Board: 2 copper layers, 207.4 x 114.9 mm, 159 parts (0 on the bottom side), 158 nets.

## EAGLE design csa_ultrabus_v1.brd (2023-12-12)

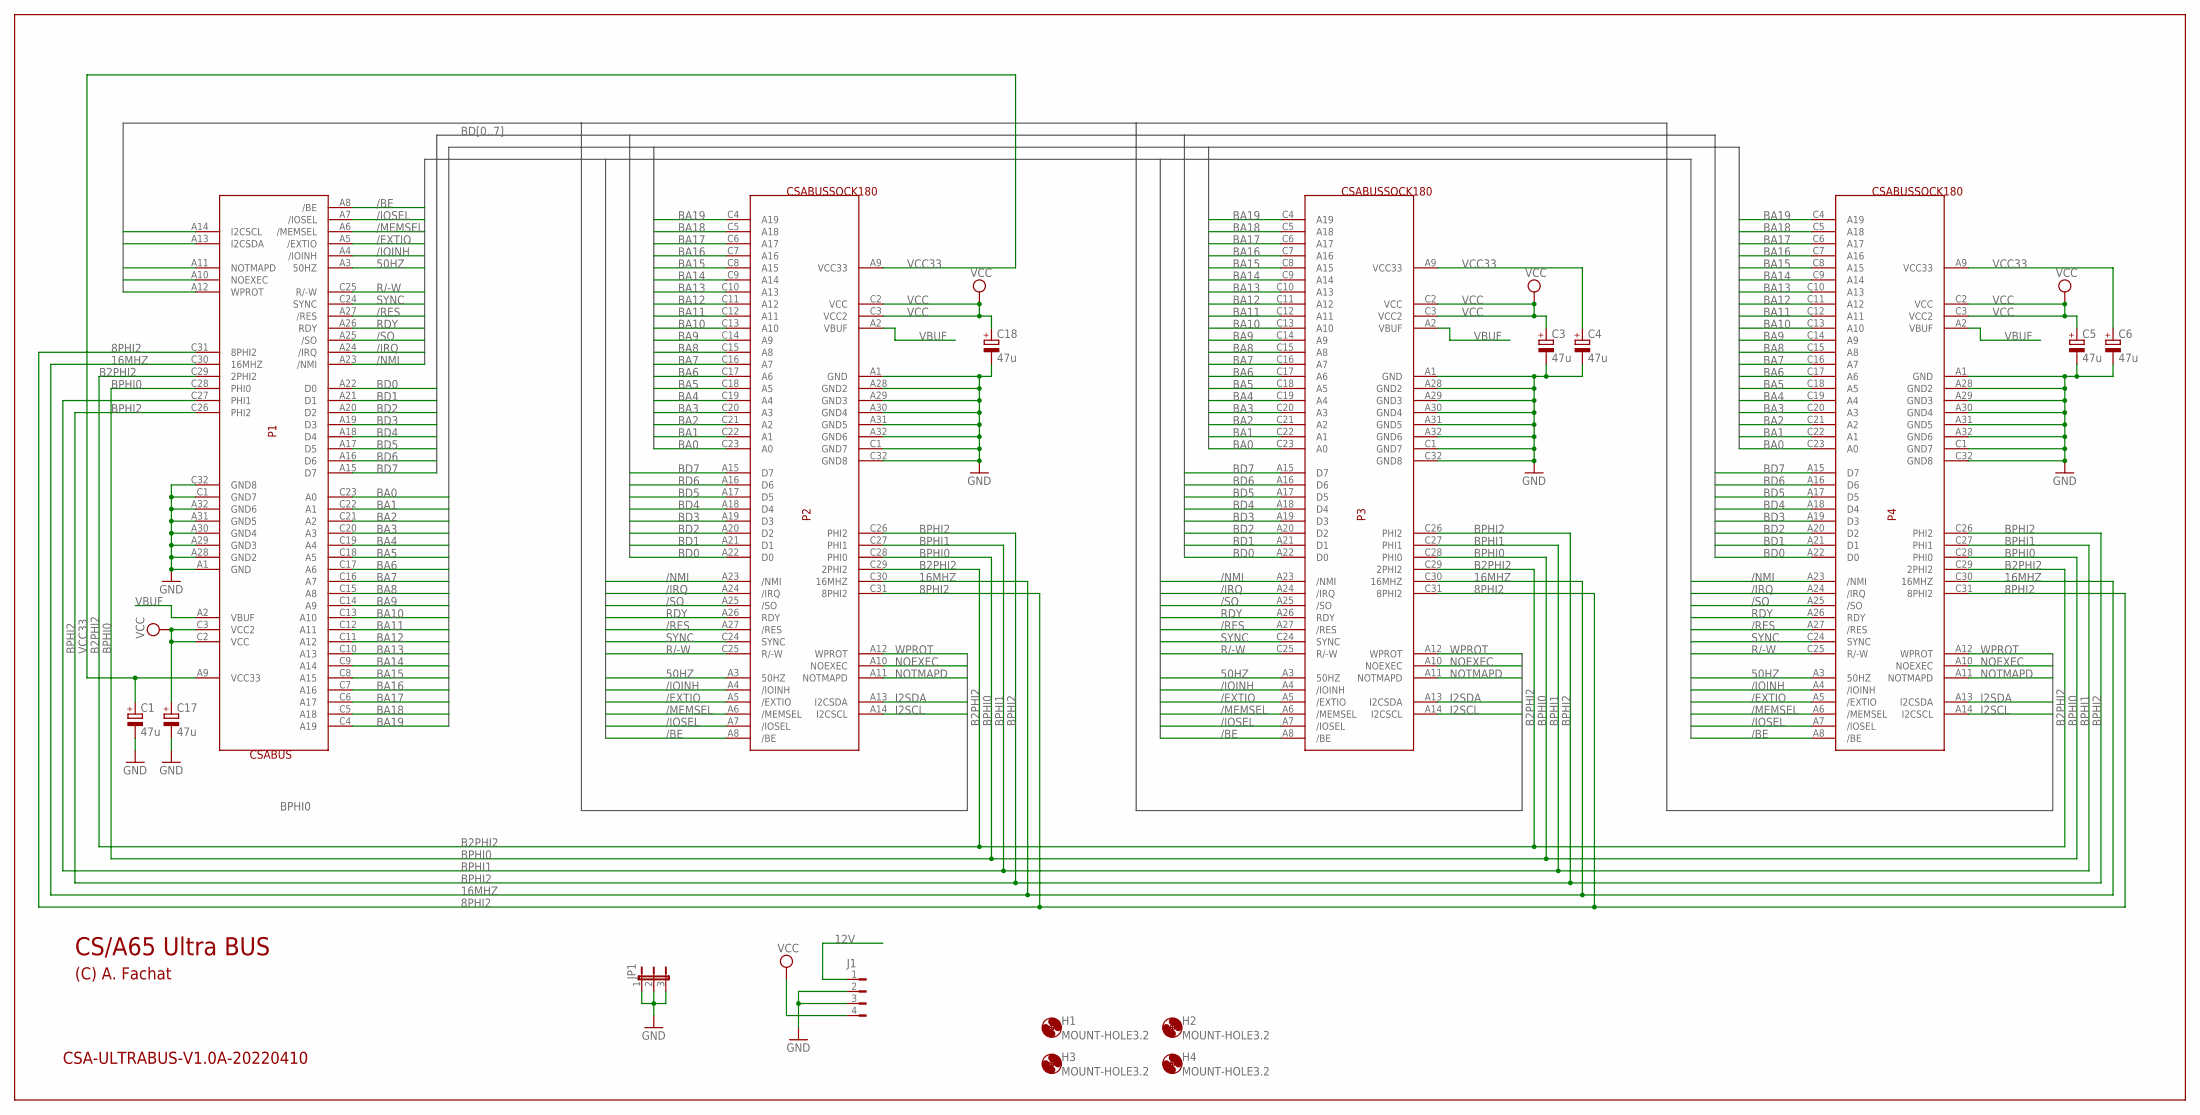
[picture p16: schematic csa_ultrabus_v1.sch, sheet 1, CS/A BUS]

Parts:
C1, C3, C4, C5, C6, C17, C18: 47u; E2,5-5
H1, H2, H3, H4: MOUNT-HOLE3.2; 3,2
J1: FLOP-4W827001; 827001
JP1: JP2E; JP2
P1: CSABUS
P2, P3, P4: CSABUSSOCK180

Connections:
8PHI2: P1.C31 (8PHI2), P2.C31 (8PHI2), P3.C31 (8PHI2), P4.C31 (8PHI2)
12V: J1.1; also elsewhere on the board
16MHZ: P1.C30 (16MHZ), P2.C30 (16MHZ), P3.C30 (16MHZ), P4.C30 (16MHZ)
50HZ: P1.A3 (50HZ), P2.A3 (50HZ), P3.A3 (50HZ), P4.A3 (50HZ)
/BE: P1.A8 (/BE), P2.A8 (/BE), P3.A8 (/BE), P4.A8 (/BE); also elsewhere on the board
/EXTIO: P1.A5 (/EXTIO), P2.A5 (/EXTIO), P3.A5 (/EXTIO), P4.A5 (/EXTIO)
/IOINH: P1.A4 (/IOINH), P2.A4 (/IOINH), P3.A4 (/IOINH), P4.A4 (/IOINH); also elsewhere on the board
/IOSEL: P1.A7 (/IOSEL), P2.A7 (/IOSEL), P3.A7 (/IOSEL), P4.A7 (/IOSEL); also elsewhere on the board
/IRQ: P1.A24 (/IRQ), P2.A24 (/IRQ), P3.A24 (/IRQ), P4.A24 (/IRQ); also elsewhere on the board
/MEMSEL: P1.A6 (/MEMSEL), P2.A6 (/MEMSEL), P3.A6 (/MEMSEL), P4.A6 (/MEMSEL); also elsewhere on the board
/NMI: P1.A23 (/NMI), P2.A23 (/NMI), P3.A23 (/NMI), P4.A23 (/NMI); also elsewhere on the board
/RES: P1.A27 (/RES), P2.A27 (/RES), P3.A27 (/RES), P4.A27 (/RES); also elsewhere on the board
/SO: P1.A25 (/SO), P2.A25 (/SO), P3.A25 (/SO), P4.A25 (/SO)
B2PHI2: P1.C29 (2PHI2), P2.C29 (2PHI2), P3.C29 (2PHI2), P4.C29 (2PHI2); also elsewhere on the board
BA0: P1.C23 (A0), P2.C23 (A0), P3.C23 (A0), P4.C23 (A0); also elsewhere on the board
BA1: P1.C22 (A1), P2.C22 (A1), P3.C22 (A1), P4.C22 (A1); also elsewhere on the board
BA2: P1.C21 (A2), P2.C21 (A2), P3.C21 (A2), P4.C21 (A2); also elsewhere on the board
BA3: P1.C20 (A3), P2.C20 (A3), P3.C20 (A3), P4.C20 (A3); also elsewhere on the board
BA4: P1.C19 (A4), P2.C19 (A4), P3.C19 (A4), P4.C19 (A4); also elsewhere on the board
BA5: P1.C18 (A5), P2.C18 (A5), P3.C18 (A5), P4.C18 (A5); also elsewhere on the board
BA6: P1.C17 (A6), P2.C17 (A6), P3.C17 (A6), P4.C17 (A6); also elsewhere on the board
BA7: P1.C16 (A7), P2.C16 (A7), P3.C16 (A7), P4.C16 (A7); also elsewhere on the board
BA8: P1.C15 (A8), P2.C15 (A8), P3.C15 (A8), P4.C15 (A8); also elsewhere on the board
BA9: P1.C14 (A9), P2.C14 (A9), P3.C14 (A9), P4.C14 (A9); also elsewhere on the board
BA10: P1.C13 (A10), P2.C13 (A10), P3.C13 (A10), P4.C13 (A10); also elsewhere on the board
BA11: P1.C12 (A11), P2.C12 (A11), P3.C12 (A11), P4.C12 (A11); also elsewhere on the board
BA12: P1.C11 (A12), P2.C11 (A12), P3.C11 (A12), P4.C11 (A12); also elsewhere on the board
BA13: P1.C10 (A13), P2.C10 (A13), P3.C10 (A13), P4.C10 (A13); also elsewhere on the board
BA14: P1.C9 (A14), P2.C9 (A14), P3.C9 (A14), P4.C9 (A14); also elsewhere on the board
BA15: P1.C8 (A15), P2.C8 (A15), P3.C8 (A15), P4.C8 (A15); also elsewhere on the board
BA16: P1.C7 (A16), P2.C7 (A16), P3.C7 (A16), P4.C7 (A16); also elsewhere on the board
BA17: P1.C6 (A17), P2.C6 (A17), P3.C6 (A17), P4.C6 (A17); also elsewhere on the board
BA18: P1.C5 (A18), P2.C5 (A18), P3.C5 (A18), P4.C5 (A18); also elsewhere on the board
BA19: P1.C4 (A19), P2.C4 (A19), P3.C4 (A19), P4.C4 (A19); also elsewhere on the board
BD0: P1.A22 (D0), P2.A22 (D0), P3.A22 (D0), P4.A22 (D0); also elsewhere on the board
BD1: P1.A21 (D1), P2.A21 (D1), P3.A21 (D1), P4.A21 (D1); also elsewhere on the board
BD2: P1.A20 (D2), P2.A20 (D2), P3.A20 (D2), P4.A20 (D2); also elsewhere on the board
BD3: P1.A19 (D3), P2.A19 (D3), P3.A19 (D3), P4.A19 (D3); also elsewhere on the board
BD4: P1.A18 (D4), P2.A18 (D4), P3.A18 (D4), P4.A18 (D4); also elsewhere on the board
BD5: P1.A17 (D5), P2.A17 (D5), P3.A17 (D5), P4.A17 (D5); also elsewhere on the board
BD6: P1.A16 (D6), P2.A16 (D6), P3.A16 (D6), P4.A16 (D6); also elsewhere on the board
BD7: P1.A15 (D7), P2.A15 (D7), P3.A15 (D7), P4.A15 (D7); also elsewhere on the board
BPHI0: P1.C28 (PHI0), P2.C28 (PHI0), P3.C28 (PHI0), P4.C28 (PHI0); also elsewhere on the board
BPHI1: P1.C27 (PHI1), P2.C27 (PHI1), P3.C27 (PHI1), P4.C27 (PHI1); also elsewhere on the board
BPHI2: P1.C26 (PHI2), P2.C26 (PHI2), P3.C26 (PHI2), P4.C26 (PHI2); also elsewhere on the board
GND: C1.-, C3.-, C4.-, C5.-, C6.-, C17.-, C18.-, J1.2, J1.3, JP1.1, JP1.2, JP1.3, P1.A1 (GND), P1.A28 (GND2), P1.A29 (GND3), P1.A30 (GND4), P1.A31 (GND5), P1.A32 (GND6), P1.C1 (GND7), P1.C32 (GND8), P2.A1 (GND), P2.A28 (GND2), P2.A29 (GND3), P2.A30 (GND4), P2.A31 (GND5), P2.A32 (GND6), P2.C1 (GND7), P2.C32 (GND8), P3.A1 (GND), P3.A28 (GND2), P3.A29 (GND3), P3.A30 (GND4), P3.A31 (GND5), P3.A32 (GND6), P3.C1 (GND7), P3.C32 (GND8), P4.A1 (GND), P4.A28 (GND2), P4.A29 (GND3), P4.A30 (GND4), P4.A31 (GND5), P4.A32 (GND6), P4.C1 (GND7), P4.C32 (GND8); also elsewhere on the board
I2SCL: P1.A14 (I2CSCL), P2.A14 (I2CSCL), P3.A14 (I2CSCL), P4.A14 (I2CSCL)
I2SDA: P1.A13 (I2CSDA), P2.A13 (I2CSDA), P3.A13 (I2CSDA), P4.A13 (I2CSDA)
NOEXEC: P1.A10 (NOEXEC), P2.A10 (NOEXEC), P3.A10 (NOEXEC), P4.A10 (NOEXEC)
NOTMAPD: P1.A11 (NOTMAPD), P2.A11 (NOTMAPD), P3.A11 (NOTMAPD), P4.A11 (NOTMAPD)
R/-W: P1.C25 (R/-W), P2.C25 (R/-W), P3.C25 (R/-W), P4.C25 (R/-W); also elsewhere on the board
RDY: P1.A26 (RDY), P2.A26 (RDY), P3.A26 (RDY), P4.A26 (RDY); also elsewhere on the board
SYNC: P1.C24 (SYNC), P2.C24 (SYNC), P3.C24 (SYNC), P4.C24 (SYNC); also elsewhere on the board
VBUF: P1.A2 (VBUF), P2.A2 (VBUF), P3.A2 (VBUF), P4.A2 (VBUF)
VCC: C3.+, C5.+, C17.+, C18.+, J1.4, P1.C2 (VCC), P1.C3 (VCC2), P2.C2 (VCC), P2.C3 (VCC2), P3.C2 (VCC), P3.C3 (VCC2), P4.C2 (VCC), P4.C3 (VCC2); also elsewhere on the board
VCC33: C1.+, C4.+, C6.+, P1.A9 (VCC33), P2.A9 (VCC33), P3.A9 (VCC33), P4.A9 (VCC33)
WPROT: P1.A12 (WPROT), P2.A12 (WPROT), P3.A12 (WPROT), P4.A12 (WPROT)

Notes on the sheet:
CSA-ULTRABUS-V1.0A-20220410
CS/A65 Ultra BUS
(C) A. Fachat


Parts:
C2, C7, C8, C9, C10, C11, C12, C16: C-EUC0603; C0603
C13, C14, C15, C19, C20, C21: 47u; E2,5-5
IC1: 74AC04D; SO14
IC2, IC3, IC4, IC5: 74AC138D; SO16
IC7, IC8: 74HCT125D; SO14
JP8, JP17: JP1E; JP1
JP9, JP10, JP11, JP15, JP16: JP2E; JP2
SLOT3, SLOT5, SLOT7: A2SLOT; FE100-25

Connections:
8MHZ: IC1.2 (O), SLOT3.P (7M), SLOT5.P (7M), SLOT7.P (7M)
12V: C19.+, C20.+, C21.+, SLOT3.A (12V), SLOT5.A (12V), SLOT7.A (12V); also elsewhere on the board
/BANK0: IC2.15 (Y0), JP15.1; also elsewhere on the board
/BANK2: IC2.13 (Y2), JP15.3
/BANK4: IC2.11 (Y4)
/BANK5: IC2.10 (Y5)
/BANK6: IC2.9 (Y6); also elsewhere on the board
/BE: IC8.3 (O); also elsewhere on the board
/DMA: JP9.3, SLOT3.22 (/DMA), SLOT5.22 (/DMA), SLOT7.22 (/DMA)
/IOINH: JP8.1; also elsewhere on the board
/IOSEL: JP16.3, JP17.2; also elsewhere on the board
/IOSTROBE: JP10.2, SLOT3.20 (/IOSTROBE), SLOT5.20 (/IOSTROBE), SLOT7.20 (/IOSTROBE)
/IRQ: SLOT3.V (/IRQ), SLOT5.V (/IRQ), SLOT7.V (/IRQ); also elsewhere on the board
/MEMSEL: IC2.5 (G2B), IC8.6 (O); also elsewhere on the board
/NMI: SLOT3.W (/NMI), SLOT5.W (/NMI), SLOT7.W (/NMI); also elsewhere on the board
/RES: SLOT3.U (/RES), SLOT5.U (/RES), SLOT7.U (/RES); also elsewhere on the board
/SLOT0IO: IC3.15 (Y0), JP16.1
/SLOT2IO: IC3.13 (Y2), JP17.1
/SLOT3IO: IC3.12 (Y3), SLOT3.1 (/IOSELECT)
/SLOT5IO: IC3.10 (Y5), SLOT5.1 (/IOSELECT)
/SLOT6IO: IC3.9 (Y6); also elsewhere on the board
/SLOT7IO: IC3.7 (Y7), SLOT7.1 (/IOSELECT)
/SLOTIO: IC3.4 (G2A), JP11.2
A2USER1: JP8.2, SLOT3.M (USER1), SLOT5.M (USER1), SLOT7.M (USER1)
B2PHI2: SLOT3.O (Q3), SLOT5.O (Q3), SLOT7.O (Q3); also elsewhere on the board
B8PHI2: IC1.1 (I)
BA0: SLOT3.2 (A0), SLOT5.2 (A0), SLOT7.2 (A0); also elsewhere on the board
BA1: SLOT3.3 (A1), SLOT5.3 (A1), SLOT7.3 (A1); also elsewhere on the board
BA2: SLOT3.4 (A2), SLOT5.4 (A2), SLOT7.4 (A2); also elsewhere on the board
BA3: SLOT3.5 (A3), SLOT5.5 (A3), SLOT7.5 (A3); also elsewhere on the board
BA4: IC4.1 (A), SLOT3.6 (A4), SLOT5.6 (A4), SLOT7.6 (A4); also elsewhere on the board
BA5: IC4.2 (B), SLOT3.7 (A5), SLOT5.7 (A5), SLOT7.7 (A5); also elsewhere on the board
BA6: IC4.3 (C), SLOT3.8 (A6), SLOT5.8 (A6), SLOT7.8 (A6); also elsewhere on the board
BA7: IC4.6 (G1), SLOT3.9 (A7), SLOT5.9 (A7), SLOT7.9 (A7); also elsewhere on the board
BA8: IC3.1 (A), SLOT3.10 (A8), SLOT5.10 (A8), SLOT7.10 (A8); also elsewhere on the board
BA9: IC3.2 (B), SLOT3.11 (A9), SLOT5.11 (A9), SLOT7.11 (A9); also elsewhere on the board
BA10: IC3.3 (C), SLOT3.12 (A10), SLOT5.12 (A10), SLOT7.12 (A10); also elsewhere on the board
BA11: IC5.1 (A), SLOT3.13 (A11), SLOT5.13 (A11), SLOT7.13 (A11); also elsewhere on the board
BA12: IC5.2 (B), SLOT3.14 (A12), SLOT5.14 (A12), SLOT7.14 (A12); also elsewhere on the board
BA13: IC5.4 (G2A), SLOT3.15 (A13), SLOT5.15 (A13), SLOT7.15 (A13); also elsewhere on the board
BA14: IC5.3 (C), SLOT3.16 (A14), SLOT5.16 (A14), SLOT7.16 (A14); also elsewhere on the board
BA15: IC5.6 (G1), SLOT3.17 (A15), SLOT5.17 (A15), SLOT7.17 (A15); also elsewhere on the board
BA16: IC2.1 (A), IC7.3 (O); also elsewhere on the board
BA17: IC2.2 (B), IC7.11 (O); also elsewhere on the board
BA18: IC2.3 (C), IC7.6 (O); also elsewhere on the board
BA19: IC2.4 (G2A), IC7.8 (O); also elsewhere on the board
BD0: SLOT3.B (D0), SLOT5.B (D0), SLOT7.B (D0); also elsewhere on the board
BD1: SLOT3.C (D1), SLOT5.C (D1), SLOT7.C (D1); also elsewhere on the board
BD2: SLOT3.D (D2), SLOT5.D (D2), SLOT7.D (D2); also elsewhere on the board
BD3: SLOT3.E (D3), SLOT5.E (D3), SLOT7.E (D3); also elsewhere on the board
BD4: SLOT3.F (D4), SLOT5.F (D4), SLOT7.F (D4); also elsewhere on the board
BD5: SLOT3.G (D5), SLOT5.G (D5), SLOT7.G (D5); also elsewhere on the board
BD6: SLOT3.H (D6), SLOT5.H (D6), SLOT7.H (D6); also elsewhere on the board
BD7: SLOT3.J (D7), SLOT5.J (D7), SLOT7.J (D7); also elsewhere on the board
BPHI1: SLOT3.N (PHI1), SLOT5.N (PHI1), SLOT7.N (PHI1); also elsewhere on the board
BPHI2: SLOT3.L (PHI0), SLOT5.L (PHI0), SLOT7.L (PHI0); also elsewhere on the board
COLORREF: SLOT3.Q (COLORREF), SLOT5.Q (COLORREF), SLOT7.Q (COLORREF)
GND: C2.2, C7.2, C8.2, C9.2, C10.2, C11.2, C12.2, C13.-, C14.-, C15.-, C16.2, C19.-, C20.-, C21.-, IC1.7 (GND), IC2.8 (GND), IC3.5 (G2B), IC3.8 (GND), IC4.5 (G2B), IC4.8 (GND), IC5.8 (GND), IC7.2 (I), IC7.5 (I), IC7.7 (GND), IC7.9 (I), IC7.12 (I), IC8.2 (I), IC8.5 (I), IC8.7 (GND), JP9.1, SLOT3.Z (GND), SLOT5.Z (GND), SLOT7.Z (GND); also elsewhere on the board
unnamed: IC7.1 (OE), IC7.4 (OE), IC7.10 (OE), IC7.13 (OE), IC8.1 (OE), IC8.4 (OE), JP9.2
unnamed: SLOT3.23 (INT_OUT), SLOT5.X (INT_IN)
unnamed: SLOT5.23 (INT_OUT), SLOT7.X (INT_IN)
unnamed: SLOT3.24 (DMA_OUT), SLOT5.Y (DMA_IN)
unnamed: SLOT5.24 (DMA_OUT), SLOT7.Y (DMA_IN)
unnamed: IC5.13 (Y2), JP11.1
unnamed: IC5.12 (Y3), JP10.1
unnamed: IC5.11 (Y4), JP11.3
unnamed: IC5.10 (Y5), JP10.3
unnamed: IC4.4 (G2A), JP16.2
unnamed: IC5.5 (G2B), JP15.2
R/-W: SLOT3.18 (R/-W), SLOT5.18 (R/-W), SLOT7.18 (R/-W); also elsewhere on the board
RDY: SLOT3.21 (RDY), SLOT5.21 (RDY), SLOT7.21 (RDY); also elsewhere on the board
SLOT0DEV: IC4.15 (Y0)
SLOT3DEV: IC4.12 (Y3), SLOT3.K (/DEVSELECT)
SLOT5DEV: IC4.10 (Y5), SLOT5.K (/DEVSELECT)
SLOT6DEV: IC4.9 (Y6)
SLOT7DEV: IC4.7 (Y7), SLOT7.K (/DEVSELECT)
SYNC: SLOT3.19 (SYNC), SLOT5.19 (SYNC), SLOT7.19 (SYNC); also elsewhere on the board
VCC: C2.1, C7.1, C8.1, C9.1, C10.1, C11.1, C12.1, C13.+, C14.+, C15.+, C16.1, IC1.14 (VCC), IC2.6 (G1), IC2.16 (VCC), IC3.6 (G1), IC3.16 (VCC), IC4.16 (VCC), IC5.16 (VCC), IC7.14 (VCC), IC8.14 (VCC), SLOT3.25 (5V), SLOT5.25 (5V), SLOT7.25 (5V); also elsewhere on the board

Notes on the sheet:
Note: There exists a best practice to not drive the Data bus before the first rising edge of 7M after Phi0 went up, to avoid bus conflicts
Currently uses any 4k window in the upper half of bank 00. This particularly matches $9xxx and $Cxxx, the two bus window options of the ULTRACPU board. This IC then selects a 256 byte area in these 2k I/O space
This selects the a 64k bank from the 1M bus address space. In the ULTRACPU these map to CPU banks $10...$17
$C7xx
$C0xx
$C08x/E88x
$C0Fx/E8Fx
On /DMA low, a) pull /BE low b) pull /MEMSEL low c) pull BA16-19 low
CS/A65 Ultra BUS
(C) A. Fachat
CSA-ULTRABUS-V1.0A-20220411
$90xx-97xx
$98xx-9Fxx
$C0xx-C7xx
$C8xx-CFxx
$C0Bx/E8Bx
$C0Dx/E8Dx
$C0Ex/E8Ex


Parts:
IC1: 74AC04D; SO14
IC6: 74HCT00D; SO14
JP2, JP3, JP4, JP5, JP6, JP7, JP14: JP2E; JP2
SLOT6.1, SLOT6.2, SLOT6.3: RC2014/650239+1R; SIL39+1R

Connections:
/BANK0: JP14.1; also elsewhere on the board
/BANK4_Q: IC6.8 (O), SLOT6.1.23 (*PHI1,/MREQ)
/BANK6: JP14.3; also elsewhere on the board
/IRQ: SLOT6.1.22 (/IRQ), SLOT6.2.22 (/IRQ), SLOT6.3.22 (/IRQ); also elsewhere on the board
/M1: IC1.4 (O), JP2.3, SLOT6.1.19 (*PHI2,/M1), SLOT6.2.19 (*PHI2,/M1)
/NMI: JP7.1; also elsewhere on the board
/RD0: IC6.6 (O), JP5.3, SLOT6.1.25 (*RDY,/RD), SLOT6.2.25 (*RDY,/RD)
/RES: SLOT6.1.20 (/RES), SLOT6.2.20 (/RES), SLOT6.3.20 (/RES); also elsewhere on the board
/SEL6: IC1.11 (I), JP3.3, JP14.2, SLOT6.2.23 (*PHI1,/MREQ)
/SLOT4IO_Q: IC6.11 (O), SLOT6.1.26 (*SYNC,/IOREQ)
/SLOT6IO: IC1.9 (I), JP6.3, SLOT6.2.26 (*SYNC,/IOREQ); also elsewhere on the board
/WR0: IC6.3 (O), JP4.3, SLOT6.1.24 (*R/-W,/WR), SLOT6.2.24 (*R/-W,/WR)
BA0: SLOT6.1.16 (A0), SLOT6.2.16 (A0), SLOT6.3.16 (A0); also elsewhere on the board
BA1: SLOT6.1.15 (A1), SLOT6.2.15 (A1), SLOT6.3.15 (A1); also elsewhere on the board
BA2: SLOT6.1.14 (A2), SLOT6.2.14 (A2), SLOT6.3.14 (A2); also elsewhere on the board
BA3: SLOT6.1.13 (A3), SLOT6.2.13 (A3), SLOT6.3.13 (A3); also elsewhere on the board
BA4: SLOT6.1.12 (A4), SLOT6.2.12 (A4), SLOT6.3.12 (A4); also elsewhere on the board
BA5: SLOT6.1.11 (A5), SLOT6.2.11 (A5), SLOT6.3.11 (A5); also elsewhere on the board
BA6: SLOT6.1.10 (A6), SLOT6.2.10 (A6), SLOT6.3.10 (A6); also elsewhere on the board
BA7: SLOT6.1.9 (A7), SLOT6.2.9 (A7), SLOT6.3.9 (A7); also elsewhere on the board
BA8: SLOT6.1.8 (A8), SLOT6.2.8 (A8), SLOT6.3.8 (A8); also elsewhere on the board
BA9: SLOT6.1.7 (A9), SLOT6.2.7 (A9), SLOT6.3.7 (A9); also elsewhere on the board
BA10: SLOT6.1.6 (A10), SLOT6.2.6 (A10), SLOT6.3.6 (A10); also elsewhere on the board
BA11: SLOT6.1.5 (A11), SLOT6.2.5 (A11), SLOT6.3.5 (A11); also elsewhere on the board
BA12: SLOT6.1.4 (A12), SLOT6.2.4 (A12), SLOT6.3.4 (A12); also elsewhere on the board
BA13: SLOT6.1.3 (A13), SLOT6.2.3 (A13), SLOT6.3.3 (A13); also elsewhere on the board
BA14: SLOT6.1.2 (A14), SLOT6.2.2 (A14), SLOT6.3.2 (A14); also elsewhere on the board
BA15: SLOT6.1.1 (A15), SLOT6.2.1 (A15), SLOT6.3.1 (A15); also elsewhere on the board
BD0: SLOT6.1.27 (D0), SLOT6.2.27 (D0), SLOT6.3.27 (D0); also elsewhere on the board
BD1: SLOT6.1.28 (D1), SLOT6.2.28 (D1), SLOT6.3.28 (D1); also elsewhere on the board
BD2: SLOT6.1.29 (D2), SLOT6.2.29 (D2), SLOT6.3.29 (D2); also elsewhere on the board
BD3: SLOT6.1.30 (D3), SLOT6.2.30 (D3), SLOT6.3.30 (D3); also elsewhere on the board
BD4: SLOT6.1.31 (D4), SLOT6.2.31 (D4), SLOT6.3.31 (D4); also elsewhere on the board
BD5: SLOT6.1.32 (D5), SLOT6.2.32 (D5), SLOT6.3.32 (D5); also elsewhere on the board
BD6: SLOT6.1.33 (D6), SLOT6.2.33 (D6), SLOT6.3.33 (D6); also elsewhere on the board
BD7: SLOT6.1.34 (D7), SLOT6.2.34 (D7), SLOT6.3.34 (D7); also elsewhere on the board
BPHI0: SLOT6.1.21 (PHI0,CLK), SLOT6.2.21 (PHI0,CLK), SLOT6.3.21 (PHI0,CLK); also elsewhere on the board
BPHI1: JP3.1; also elsewhere on the board
BPHI2: IC6.2 (I1), IC6.4 (I0), JP2.1; also elsewhere on the board
GND: IC1.7 (GND), IC6.7 (GND), SLOT6.1.17 (GND), SLOT6.2.17 (GND), SLOT6.3.17 (GND); also elsewhere on the board
unnamed: JP2.2, SLOT6.3.19 (*PHI2,/M1)
unnamed: JP3.2, SLOT6.3.23 (*PHI1,/MREQ)
unnamed: JP4.2, SLOT6.3.24 (*R/-W,/WR)
unnamed: IC1.8 (O), IC6.13 (I1)
unnamed: JP5.2, SLOT6.3.25 (*RDY,/RD)
unnamed: JP6.2, SLOT6.3.26 (*SYNC,/IOREQ)
unnamed: IC1.6 (O), IC6.1 (I0)
unnamed: IC1.10 (O), IC6.10 (I1)
unnamed: JP7.2, SLOT6.3.37 (*/NMI,USER1)
R/-W: IC1.5 (I), IC6.5 (I1), IC6.9 (I0), IC6.12 (I0), JP4.1; also elsewhere on the board
RDY: JP5.1; also elsewhere on the board
RX: SLOT6.1.36 (RX), SLOT6.2.36 (RX), SLOT6.3.36 (RX)
SYNC: IC1.3 (I), JP6.1; also elsewhere on the board
TX: SLOT6.1.35 (TX), SLOT6.2.35 (TX), SLOT6.3.35 (TX)
USER1: JP7.3, SLOT6.1.37 (*/NMI,USER1), SLOT6.2.37 (*/NMI,USER1)
USER2: SLOT6.1.38 (EX1/USER2), SLOT6.2.38 (EX1/USER2), SLOT6.3.38 (EX1/USER2)
USER3: SLOT6.1.39 (EX2/USER3), SLOT6.2.39 (EX2/USER3), SLOT6.3.39 (EX2/USER3)
USER4: SLOT6.1.40 (USER4), SLOT6.2.40 (USER4), SLOT6.3.40 (USER4)
VCC: IC1.14 (VCC), IC6.14 (VCC), SLOT6.1.18 (VCC), SLOT6.2.18 (VCC), SLOT6.3.18 (VCC); also elsewhere on the board

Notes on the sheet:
Only slot with /MEMRQ and /IORQ qualified with PHI2 (e.g. needed by 6850 based serial RC2014 card)
CSA-ULTRABUS-V1.0A-20220411
(C) A. Fachat
CS/A65 Ultra BUS


Board: 2 copper layers, 160.0 x 100.0 mm, 59 parts (0 on the bottom side), 107 nets.

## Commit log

2023-12-12 add schematics and gerbers
    [csa_ultrabus_v1.brd, csa_ultrabus_v1.sch]
2024-06-20 revision 2.0b
    [Apple_II_Bus.kicad_sch, C64.kicad_sch, CS%2fA_BUS.kicad_sch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]
2024-06-20 file cleanup
    [Apple_II_Bus.kicad_sch, C64.kicad_sch, CS%2fA_BUS.kicad_sch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]
2026-03-01 add usb-c pd power supply adapter
    [BOM-usbpd-adapter.csv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]
2026-03-17 pdf schematics
2026-04-25 usb power adapter 1.1a
    [BOM-usbpd-adapter.csv, negvolt.kicad_sch, posvolt.kicad_sch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]
2026-05-09 update wrong resistors in pwrtest board
    [BOM-usbpd-adapter.csv, negvolt.kicad_sch, posvolt.kicad_sch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]
2026-08-16 adding undervoltage detection circuits
    [negvolt.kicad_sch, posvolt.kicad_sch, pwrdetect.kicad_sch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]
2026-08-17 new pwr adapter layout
    [BOM-usbpd-adapter.csv, negvolt.kicad_sch, pwrdetect.kicad_sch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]
2026-08-18 add 0V in main pwr outputs
    [BOM-usbpd-adapter.csv, negvolt.kicad_sch, posvolt.kicad_sch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]
2026-08-28 new usb controller
    [BOM-usbpd-adapter.csv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]
2026-08-29 add note for broken TL431 layout
    [pwrdetect.kicad_sch, usbpd-adapter.kicad_sch]
2026-08-30 note on tl431 circuits
    [pwrdetect.kicad_sch]
2026-08-30 updated schematics (untested)
    [negvolt.kicad_sch, posvolt.kicad_sch, pwrdetect.kicad_sch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]
2026-09-05 usb pd updated
    [negvolt.kicad_sch, posvolt.kicad_sch, pwrdetect.kicad_sch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]
2026-09-07 layout ubus 2.1a
    [Apple_II_Bus.kicad_sch, C64.kicad_sch, CS%2fA_BUS.kicad_sch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]
2026-09-07 add 3.3V and 9V to usb pwr
    [negvolt.kicad_sch, posvolt.kicad_sch, pwrdetect.kicad_sch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]
2026-09-09 update usb-c pwr adapter with mounting holes
    [BOM-usbpd-adapter.csv, negvolt.kicad_sch, posvolt.kicad_sch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]
2026-09-10 update pwr test pcb for production
    [CPL-usbpd-adapter.csv, usbpd-adapter-CuBottom.gbr, usbpd-adapter-CuTop.gbr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]
2026-09-10 add missing cbmio schem files, cleanup pwr test gerbers
    [usbpd-adapter-CuBottom.gbr, usbpd-adapter-CuTop.gbr, usbpd-adapter-EdgeCuts.gbr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]
2026-09-13 fix footprint for term blocks in usb pwr adapter
    [usbpd-adapter.kicad_pcb]
2026-09-13 remove pwrtest (moved to pcb_bits)
    [BOM-usbpd-adapter.csv, negvolt.kicad_sch, posvolt.kicad_sch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]
